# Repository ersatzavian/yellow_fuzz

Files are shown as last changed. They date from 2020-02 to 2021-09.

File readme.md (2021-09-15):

# Graduator

## What?

A bass fuzz for my good friend! Don't tell him, it's a surprise. Starting with a Boss MT-2 (I know, ew, don't tell anybody) because that's allegedly how Arion Salazar got most of his fuzz tone's on Third Eye Blind's self-titled (check out 2:20-2:30 in Graduate, of 4:10 in Thanks a Lot if you like yours with phaser). Hell yeah we want that, don't pretend you don't like that record. 

Formerly "yellow fuzz" after BRC's "yellow bikes" that happen to be green. Didn't like the sound of it, now it's the Graduator.

### Rev 01

Rev01 (non form-factor) has been built, brought up, and play tested. 

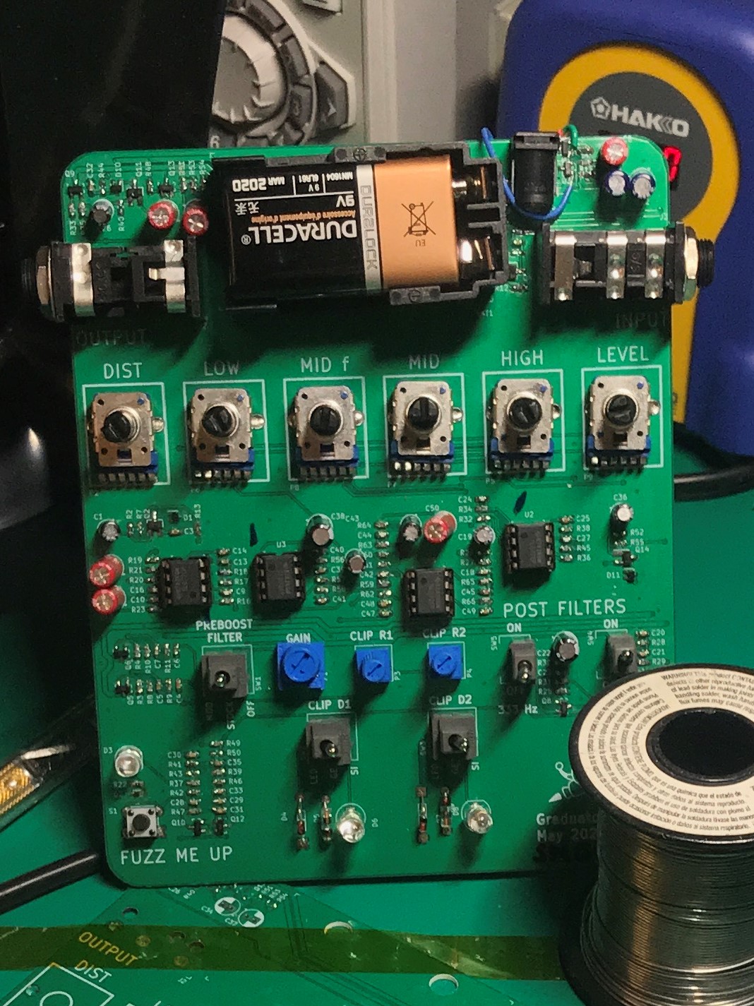
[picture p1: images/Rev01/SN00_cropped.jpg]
SN00


## Rev01 User Guide

[Electric Druid](https://electricdruid.net/boss-mt-2-metal-zone-pedal-analysis/) has an awesome write-up on the key circuit blocks in the original MT-2 design that's worth a read. If you want a comprehensive survey of the guts of this pedal, read that, then the mods section below, and you're done. 

### Controls

Controls are described by order in the signal chain, rather than physical layout. 

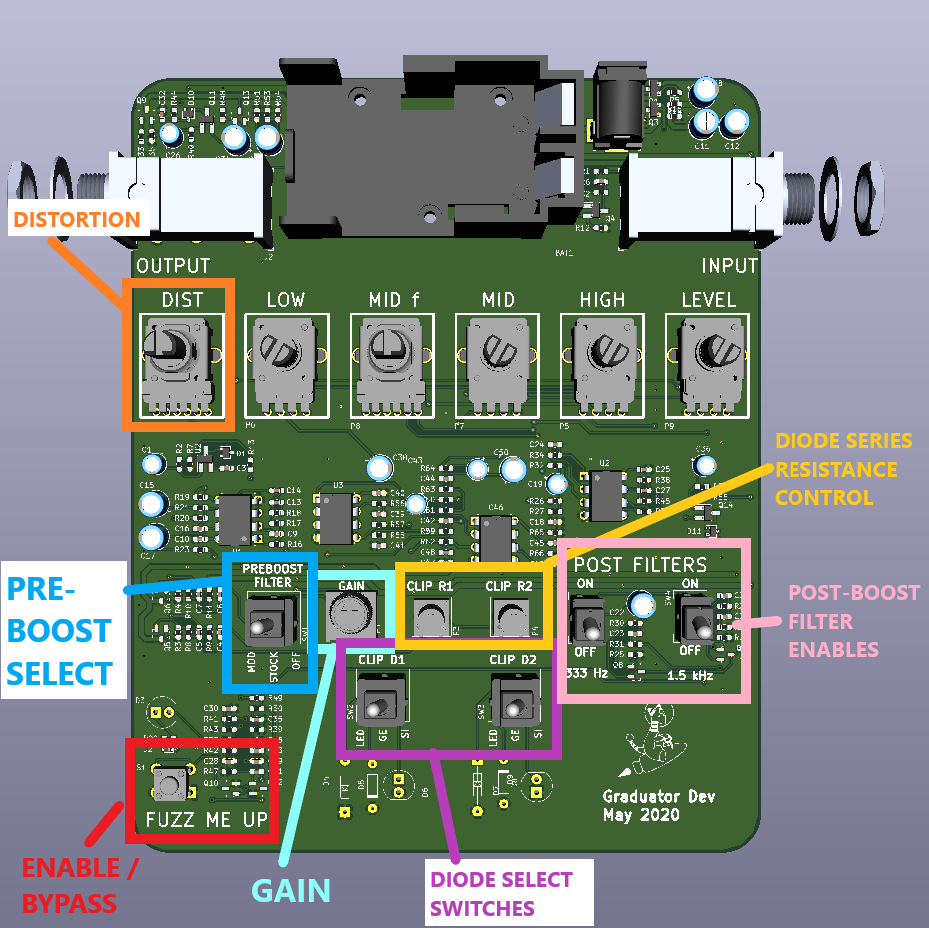
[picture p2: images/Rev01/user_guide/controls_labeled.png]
Rev01 Controls Labeled


| Control | Original MT-2 Control, or Experiment | Circuit Block | What's it Do? |
| --- | --- | --- | --- |
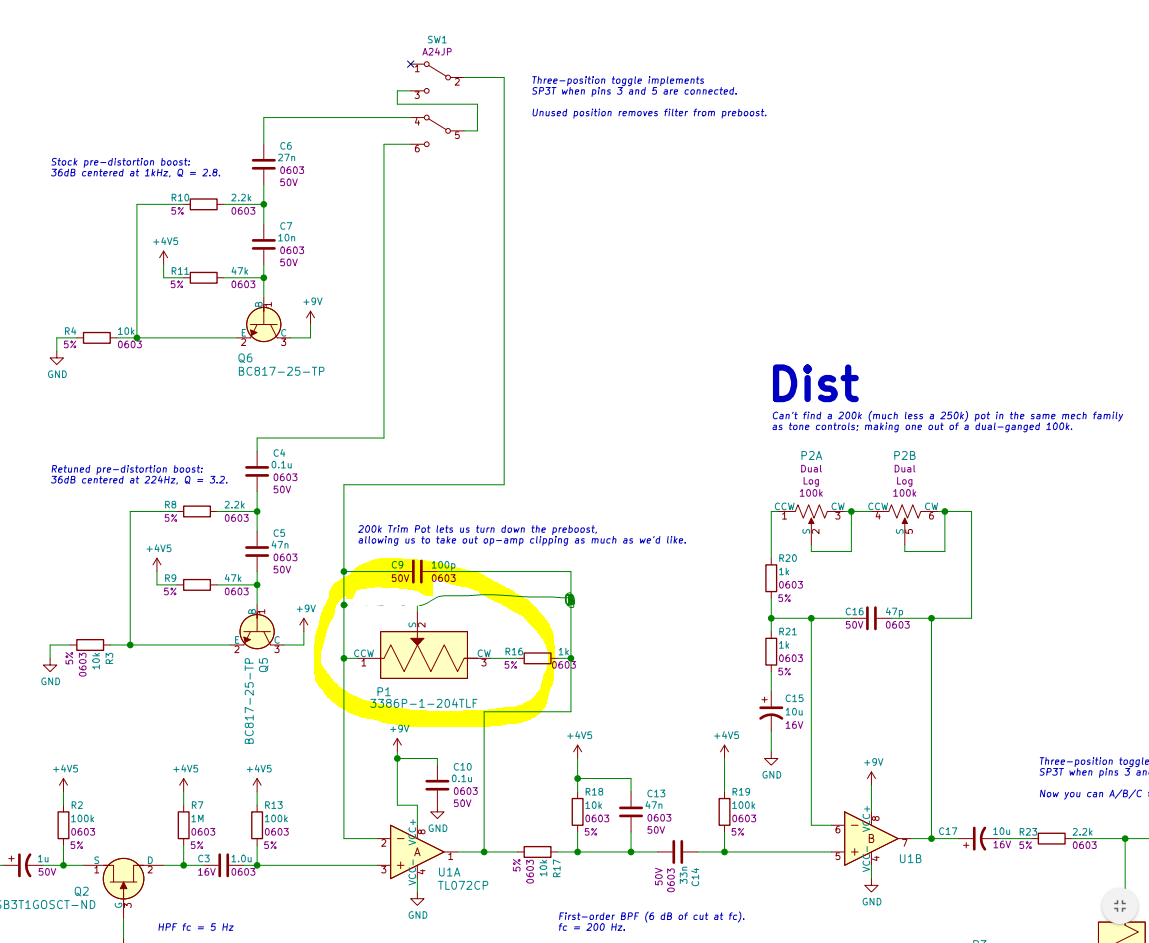
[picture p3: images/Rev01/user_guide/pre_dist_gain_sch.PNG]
Gain
| Gain | Experiment | Distortion Block - First Op-Amp Stage Gain, P1.  | The "pre-distortion" gain block does two things: <ul><li> Applies a band-pass-filtered boost (the center frequency of this boost has a mod described separately). </li><li> Demands enough gain from op amp U1A to cause some distortion when at high gain setttings. </li></ul> In the original MT-2, the gain of this stage is fixed. In the graduator, the feedback resistance here can be reduced, which reduces the gain. If the pre-boost filter is ignored (or the pre-boost filter select switch is used to skip the pre-boost filter), this control doesn't really do much at all; the end result of reducing the gain here is audibly identical to reducing the "Distortion" control. But with a filter selected, this control lets you choose how much that initial band-pass boosts, which can be kind of interesting. Definitely won't be included in the form factor design, but merits playing around with while you're playing the the pre-boost filter select. |
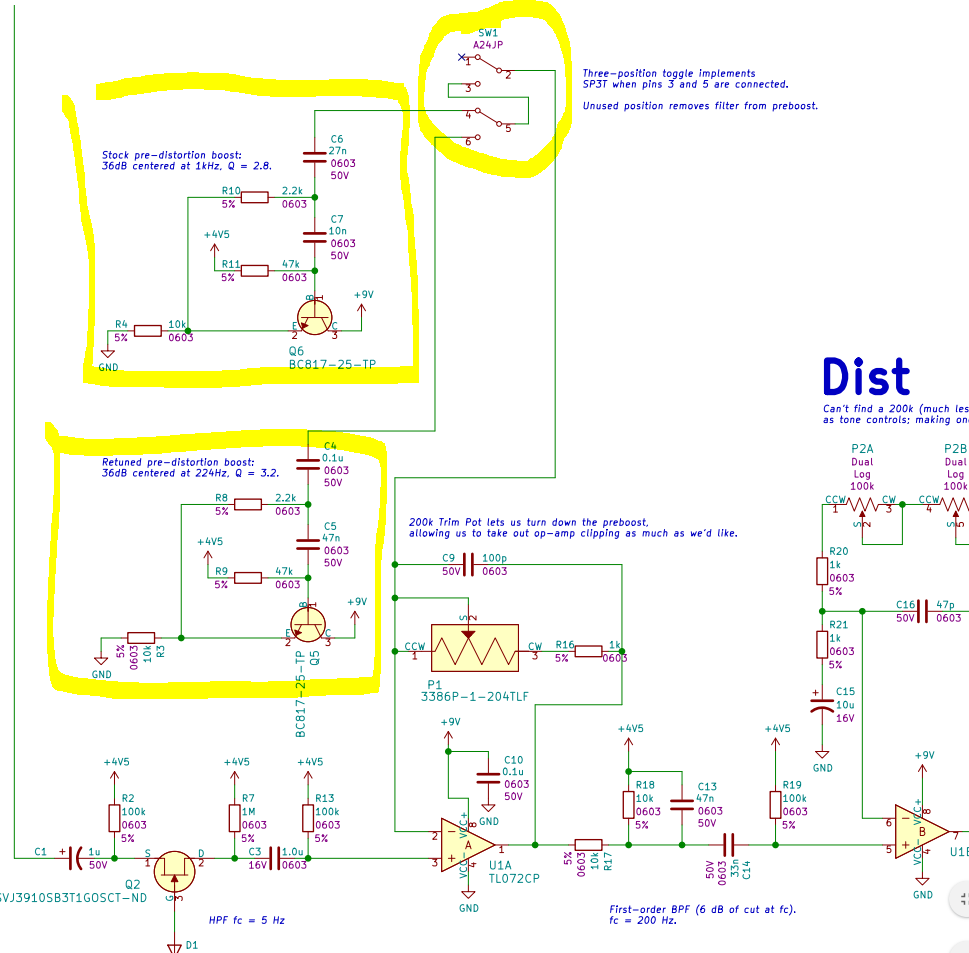
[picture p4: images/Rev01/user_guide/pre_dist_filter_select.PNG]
Pre-Boost Filter Select
| Pre-Boost Filter Select | Experiment | Distortion Block - First Op-Amp Stage Gyrator Select, SW1.  | As you can read about [here](https://sound-au.com/articles/gyrator-filters.htm), "gyrators" are nifty little active circuit blocks that let you make a thing that acts like an inductor out of a capacitor and a transistor or op-amp. Why not just use an inductor is a good question and is covered in that guide in good detail. For our purposes here, this control lets you pick between two filters, or a third disable setting: <ul><li> A stock filter which is described in the electric druid guide; it's a 36dB boost centered at 1 kHz with a "Q" of 2.8 ("Q", or "Quality Factor" describes how narrow and pointy that bandpass's frequency response is; a filter with high "Q" will be super pointy and really impact just its center frequency, while a filter with lower "Q" will be more gradual and wide and impact frequencies up and down the band around its center.).</li><li> A modified filter: 36 dB boost centered at 224 kHz, with a Q of 3.2. I made this mod to push the boost down into a range I thought might be better for a bass fuzz. </li><li> The disable setting just floats the switch terminal, which is kinda a bug because it takes the feedback (the "gain" control) out of the mix. You'll notice some volume variation going to and from this setting depending on where the "gain" is set. I may fix it. I may not. </li></ul>A bonus feature of this section is that one or both of these filter blocks could be retuned by changing a few parts, letting you do A/B comparison between a setting you like and a new setting you're considering. |
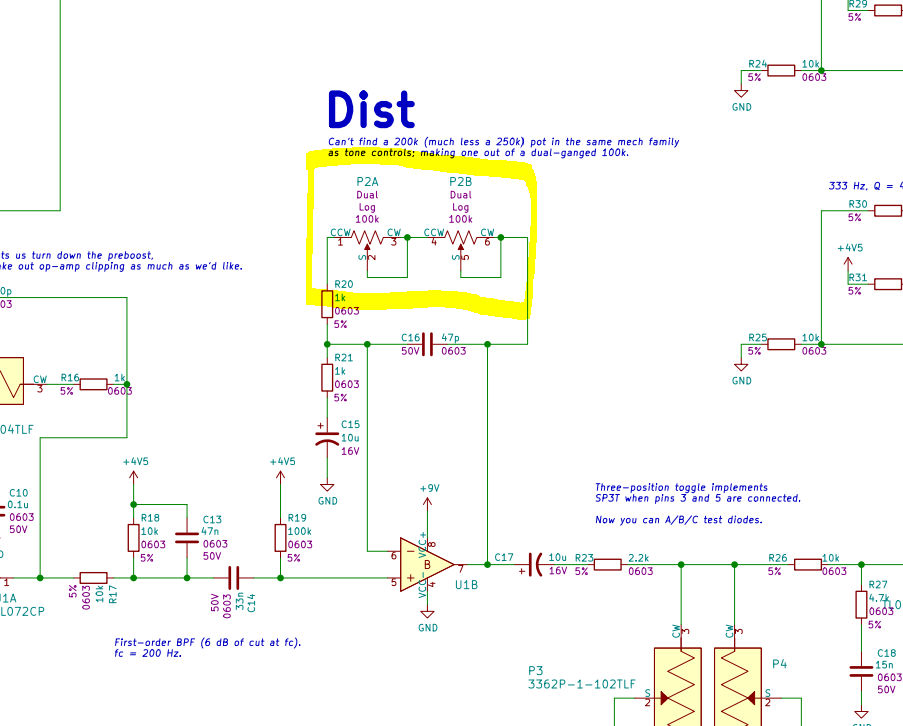
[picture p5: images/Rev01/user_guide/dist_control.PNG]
Distortion
| Distortion | Original | Distortion Block - Second Op-Amp Stage Gain, P2A/B.  | Controls the gain of the second op-amp stage before the diode limiter that really clips the signal. Running this op-amp at high gain will boost the signal to the "rails", and you'll get very hard, square peaks, before you even hit the diode limiter. There are many different sources of distortion in this pedal, it's definitely not all up to just one circuit block to hammer your signal into a mess. |
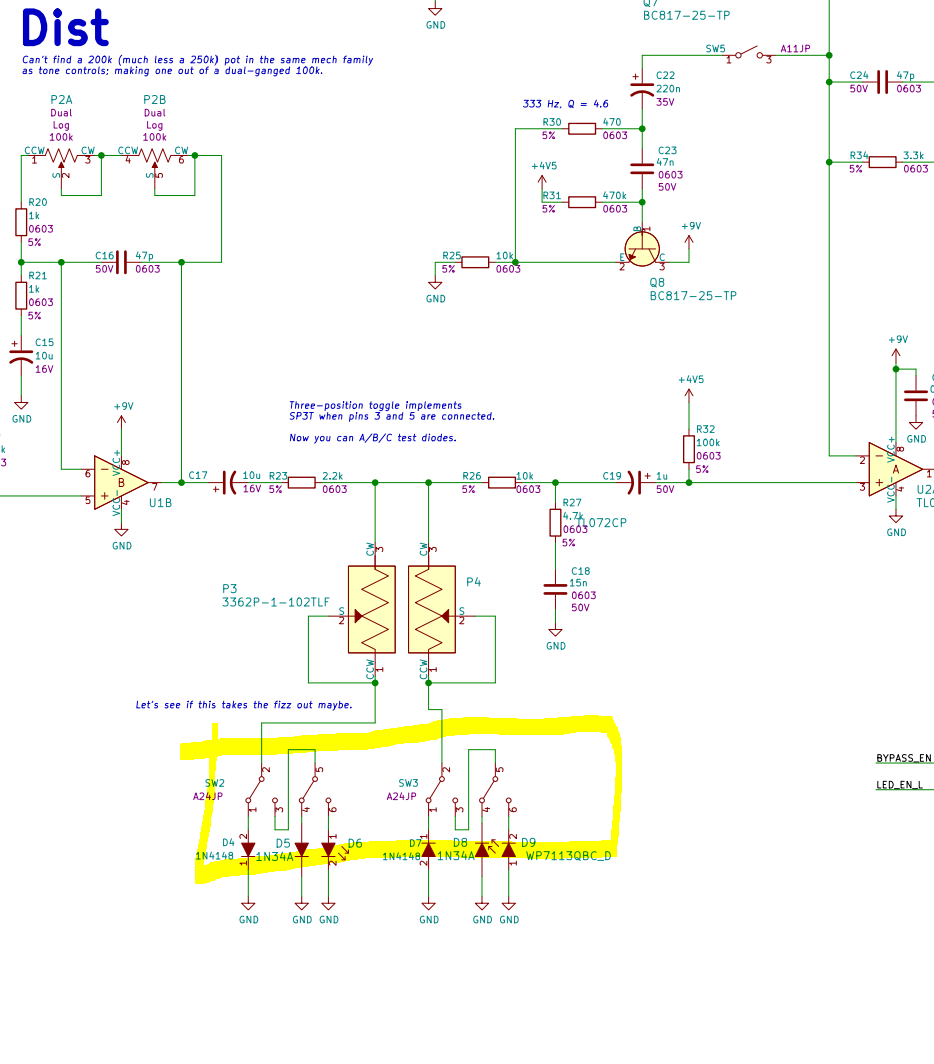
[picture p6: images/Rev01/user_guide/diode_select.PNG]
Diode Select
| Diode Select Switches | Experiment | Distortion Block - Diode Limiting Stage, SW2 / SW3  | The core of this pedal, as with many distortion pedals, is the diode limiter. This stage takes your nice sine-shaped waveform and clips the peaks off of it when they exceed the forward voltage of the diodes. Different diodes have different forward voltages, and different response "shapes" as they effectively turn on and off. The internet is full of forums where people will swear that this diode does this or that and sounds this way or that way, and many of them are subjectively right but nearly all of them are oversimplifying the test case they're talking about. Since there are so many sources of distortion in this (and every) circuit, you're hearing them all. The diode is just part of it. Anyway, this mod lets you pick between three different kinds of diode for your limiter. Even weirder, it lets you choose the diode for the top and bottom half of your waveform separately, so you can produce very "asymmetric" distortion. Right now, you have: <ul><li> A Silicon diode, the generic [1N4148](https://www.diodes.com/assets/Datasheets/ds12019.pdf), with a forward voltage around 1V. </li><li> A Germanium diode, the generic [1N34A](https://www.nteinc.com/specs/original/1N34A.pdf), with a forward voltage around 1V. </li><li> An LED, [Kingbright WP7113QBC/D](https://www.mouser.com/datasheet/2/216/WP7113QBC-D-58299.pdf). This is a blue LED, and has a forward voltage of not less than 2.4V. This is really a bug; I should have used a red or yellow LED with a forward voltage closer to the other two, so that you could compare tone without comparing volume - you'll notice right away that the blue LED is louder than the other diodes. I like how it sounds, though, so I'm considering that a future experiment and letting it ride. </li></ul> Just like the pre-distortion boost section, this section is a great place to swap out components you're curious about and A/B test stuff. |
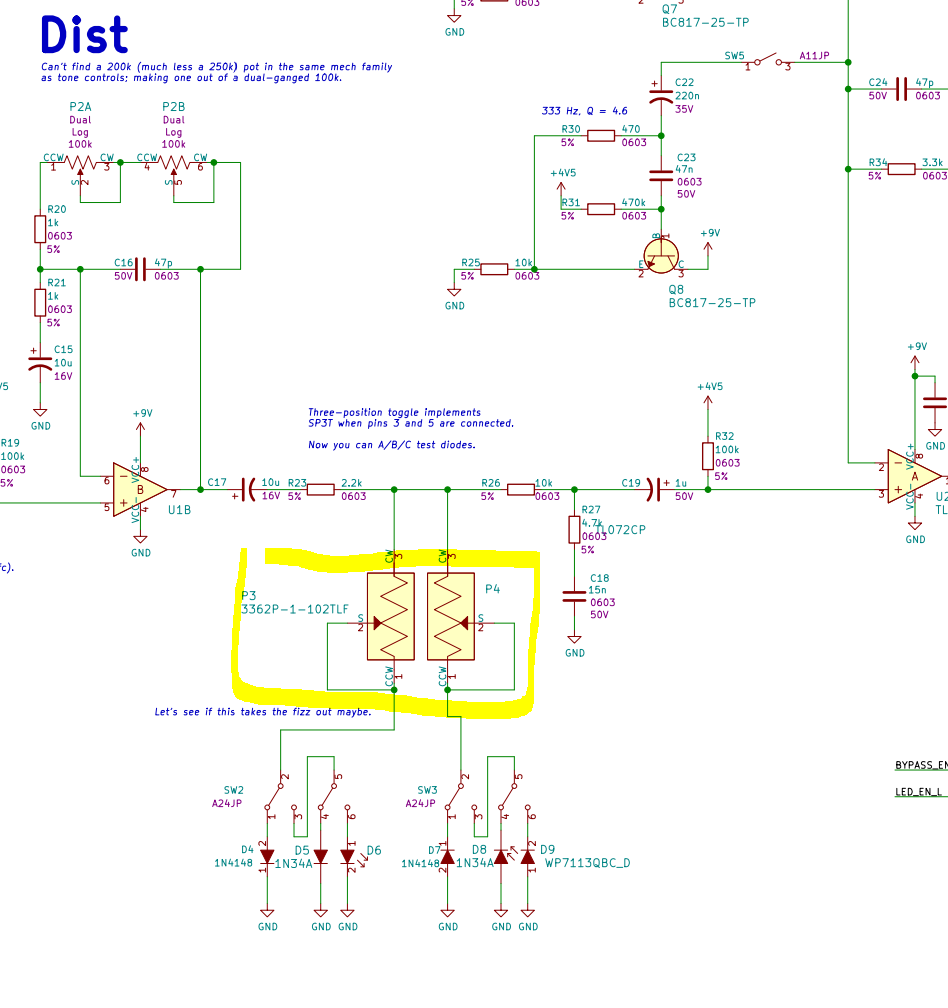
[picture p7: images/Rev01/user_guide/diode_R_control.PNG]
Diode Resistance Control
| Diode Series Resistance Control | Experiment | Distortion Block - Diode Limiting Stage, P3 / P4.  | Diode clipping can be very harsh and introduce harmonics that you wouldn't get from, say, output stage distortion in a tube amplifier, which can sound really buzzy and cheap and not great. In an attempt to prevent this, I added 1k potentiometers - variable resistors - in series with the diodes, to soften the "knee" when they turn on and off and try and reduce that fuzz. In practice, the EQ section of this pedal has way, way more impact on the harmonic content that makes it out of the pedal, and I find this control completely inaudible. |
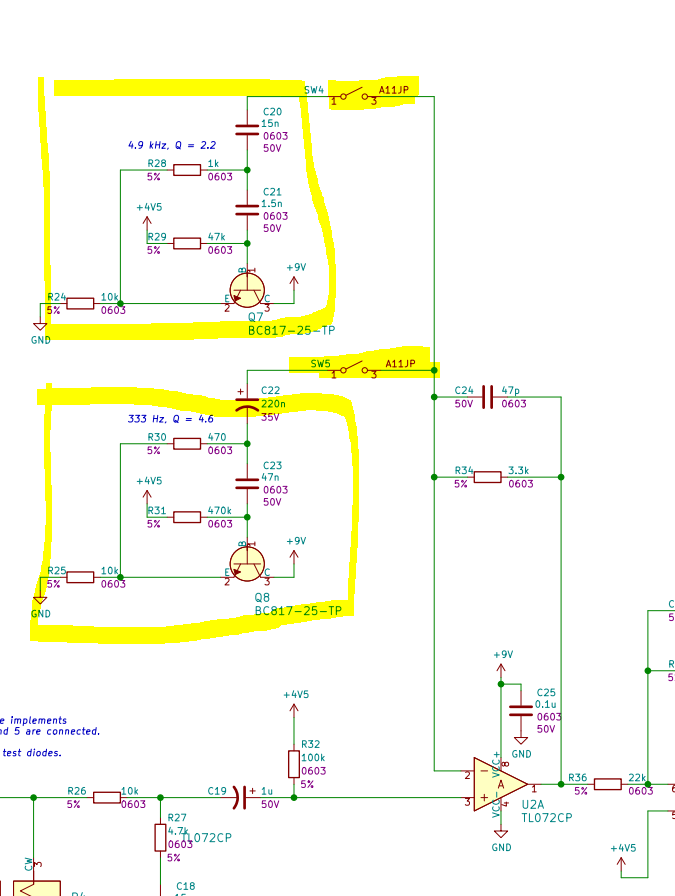
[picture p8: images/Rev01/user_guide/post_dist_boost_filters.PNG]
Post Boost Filter Control
| Post-Boost Filter Enables | Experiment | Distortion Block - after Diode Limiting Stage, SW4 / SW5.  | The original MT-2 includes this stage with both Gyrator sections included, which provides a "double-humped" bandpass boost. In the original, the two sections are: <ul><li> A ~5dB boost at 105 Hz with Q=14.6. </li><li> A ~10dB boost at 4.9 kHz with Q=2.2. </li></ul>In the graduator, the two sections are: <ul><li> A ~5dB boost at 333 Hz with Q=4.6. </li><li> The original ~10dB boost at 4.9 kHz with Q=2.2. </li></ul>There are really two mods here: <ul><li> I've moved the lower peak up the frequency spectrum and fattened it up a bit. </li><li> Both peaks can be enabled or disabled with the respective switches. </li></ul> This is a little more subtle to play with than I expected, and I like that. Try it out. |
| EQ - Low | Original | Tone Block | The original "low shelf" control, a band-pass filter centered at 105 Hz with a Q of 3.1, which can provide up to 20dB of cut or boost. The whole EQ section is covered very nicely with plots in the Electric Druid guide, highly recommend. |
| EQ - Mid Frequency | Original | Tone Block | The original "mid frequency" control, which controls the center of the mid band-pass filter. Filter center frequency can be swept from about 200 Hz to about 7 kHz. This control would be a lot better as a log taper pot, to spread the frequencies of interest logarithmically along the range of the pot, but a dual-ganged log-taper 50kΩ pot is not an easy thing to find. As a result, you'll hear this control really come to life between about 1 o-clock and 5 o-clock. |
| EQ - Mid | Original | Tone Block | Cut or boost up to 15 dB with the mid-band filter centered wherever you put it with the Mid Frequency knob. |
| EQ - High | Original | Tone Block | High Shelf EQ, begins to kick in around 1kHz, where it offers around 6 dB of cut or boost, and flattens around 10 kHz, where it offers around 20 kHz of cut or boost. | 
| Level | Original | Tone Block | You know what this does. | 
| Enable / Bypass | Original | Switching Section | You know what this does too. |

## Mods

| Change | Goal | Done |
| --- | ---- | ---- |
| Make gyrators after clipping stage optional (see C24/C25, C20/C17) | Experiment with pedal character to reduce fizz and deliver more even tone to the eq section so I can hear the difference. | Yes |
| Add bypass option for preboost stage. | Try to reduce fizz. | Yes |
| Add series variable resistors (trim pots) to clipping diodes D3/D4. | Try to reduce fizz. | Yes |
| Add selector switch for 3 different diode options in each direction. | Experiment with higher Vf (LEDs) and give germanium a whirl. | Yes |

## Issues

### Rev01 (Non-Form-Factor)

| Issue | Workaround | Fix | Fixed in Master |
| ----- | --- | --- | --- |
| C2 and R6 ref designators are swapped. HTML BOM shows correct outlines. | Install per HTML BOM. | Swap ref des back. | |
| R4, R6-7, R12, R14-15, R17-18, R24-26, R33, R51 MPN is for 1k part, should be 10k (part description on BOM is correct, but MPN is wrong). | Install 10k part. | Update component in lib. | | 
| R14 and R15 ref des are colliding. | N/A | Fix in layout. | |
| NSVJ3910SB3T1G was replaced in order with J113, which is a through-hole part and won't fit. | Order correct part. | Make sure MPN in design is correct and orderable. | |
| PTV111-4420-A104 was missing from kit, got extra PTV112-4420-A104 instead. | Cut leads 1 and 2, bend 3-6 down to fit into pads 1-4 to use just one pot of the two in the package. | Order the right thing. | |
| PTV111-4420-A503 was missing from kit, got extra PTV112-4420-A503 instead. | Cut leads 1 and 2, bend 3-6 down to fit into pads 1-4 to use just one pot of the two in the package. | Order the right thing. | |
| Nichicon UST1H010MDD1TE footprint is wrong (C1, C19, C26, C36, C43, C46): lead spacing is nto correct, part leads are flared for wider spacing than footprint. | Bend leads back. | Correct footprint. | | 
| D6 missing MPN info. | N/A | Correct part library ref. | |
| No test points, doh. | N/A | Add some ground test points and stage-to-stage test points and jumpers. | |
| 22 Ohm series-R on power rail, why even would you do that? | Short that. | Remove that. | |
| Polarity marks on op-amps are not visible enough, and are obscured when sockets are installed (U1 was installed rotated 180 degrees in first build). | Note polarity carefully during build. | Improve op amp polarity marks. | |
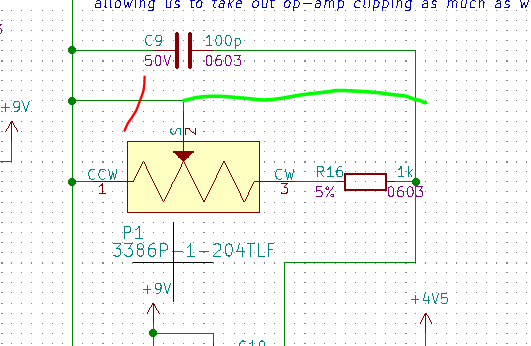
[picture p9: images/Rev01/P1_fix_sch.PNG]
Sch
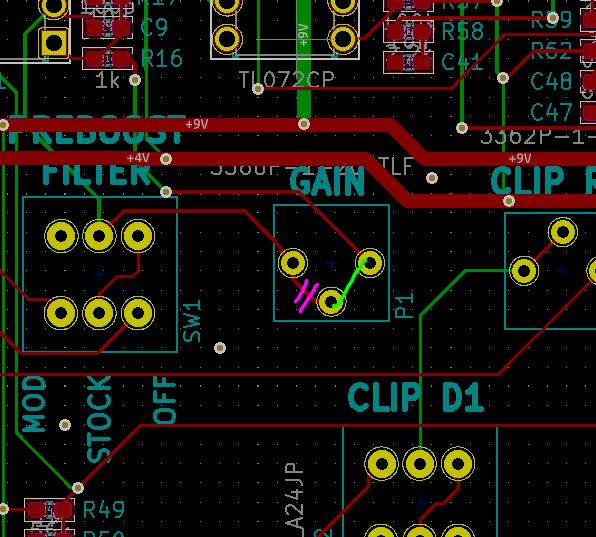
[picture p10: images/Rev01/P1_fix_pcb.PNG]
Layout
| Pre-distortion boost gain pot P1 is backwards (CCW for more) | Turn it the other way, or snip top-side trace between pins 1-2, short pins 1-3.   | Correct in schematic. | |
| Dual pots installed in P5, P6, P7, and P9 with pins 3-6 slid over into pads 1-4 don't match design correctly. | Double-check pinout of these parts and revise rework used to place dual pots in single-pot footprints. | Use the parts on the BOM, duh. | |
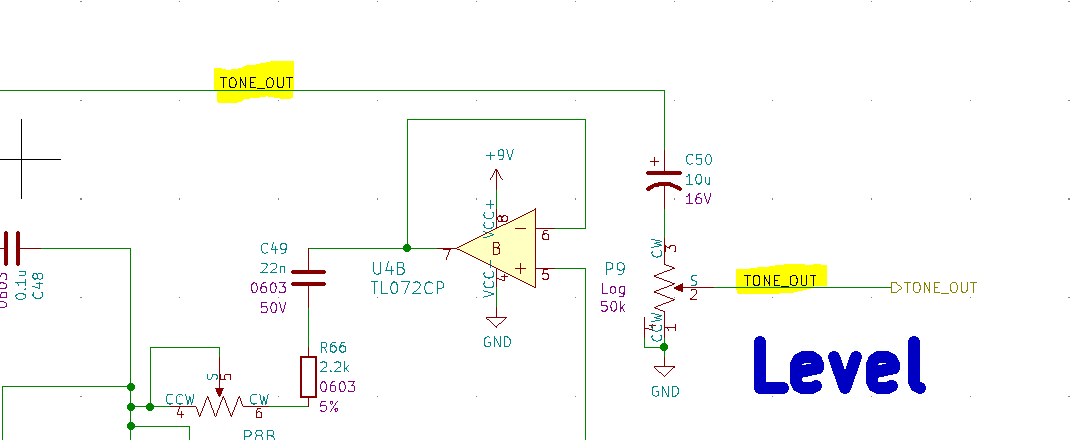
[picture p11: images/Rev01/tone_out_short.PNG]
Tone Out Issue
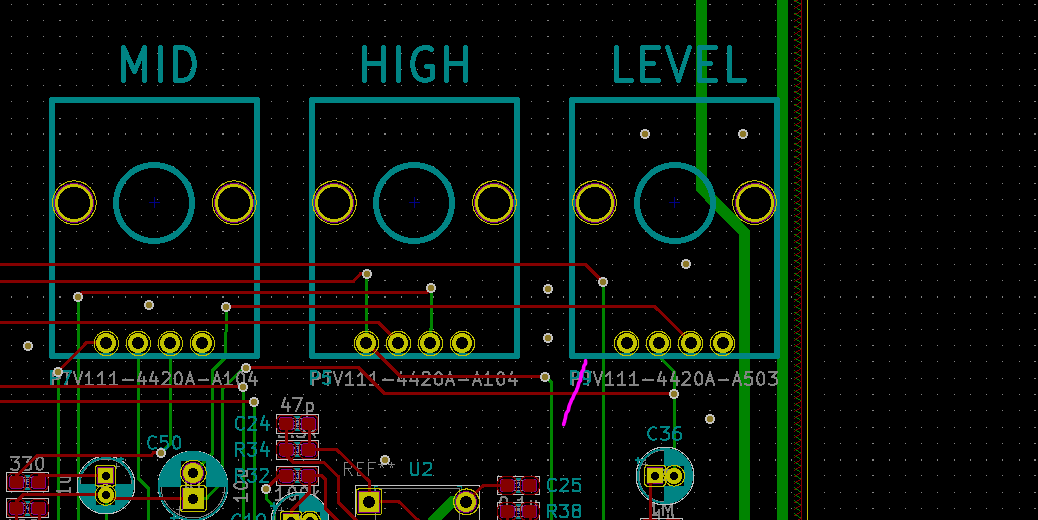
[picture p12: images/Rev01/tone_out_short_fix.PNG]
Tone Out Workaround
| Duplicate TONE_OUT net names caused short across level pot.  | Cut extra trace on top layer.  | Remove duplicate net label. | |
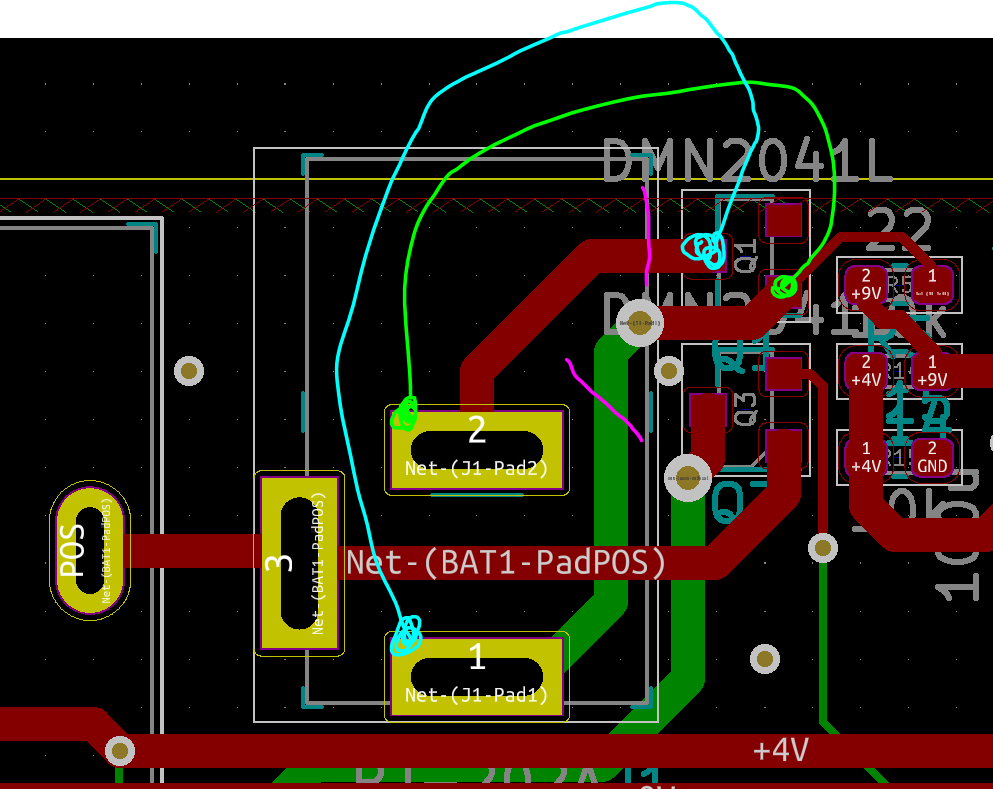
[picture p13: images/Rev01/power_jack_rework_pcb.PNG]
Jack Rework
| Incorrectly routed jack as center-positive, which makes the battery not work at all. | Cut and swap traces to make center-negative.  | Permanentify rework. | |
| Mid frequency control only does much between about 1-o-clock and 5-o-clock. | Use as is. | Try once more to find a log pot... good luck. | |
| Pre-boost filter select switch SW1 should probably have a resistor on its unused pole, rather than having fixed gain and taking the "gain" control out of the mix. |  |  |  |

## Parts Needed

### For Rev02 (Form-Factor)
* 1/4" Stereo Jack, Panel Mount with header footprint.
* 1/4" Mono Jack, Panel Mount with header footprint
* Re-evaluate all potentiometer tapers and footprints.

## Play testing notes

* It sounds... like an MT-2 with some stuff changed. 
* The pre-filter change is the most interesting, as swapping diode types. 
* Post-filters are also interesting, but a bit less so. 
* Still many settings that produce lots of unpleasant fizz. Tonally I'd still say it's "mostly bad with the ability to do some good things."
* Series-R on the dioes does exactly nothing. On the scope, it does visibly soften the knees a little, but by the time this has been through the tone section, that does the same thing. 
* Secondary control on the initial boost gain does exactly the same thing as the drive control. Might try playing with it a bit more with the pre-filter set to off, but for the most part just set it to 10 and leave it. 

## References

### Other Pedals I'm eyeing
* DOD FX91 Bass Overdrive
* Darkglass - Duality
* Zvex - Wooly Mammoth
* Death by Audio - Fuzz War
* Bass Big Muff
* MXR Bass Fuzz
* Fairfield Barbershop

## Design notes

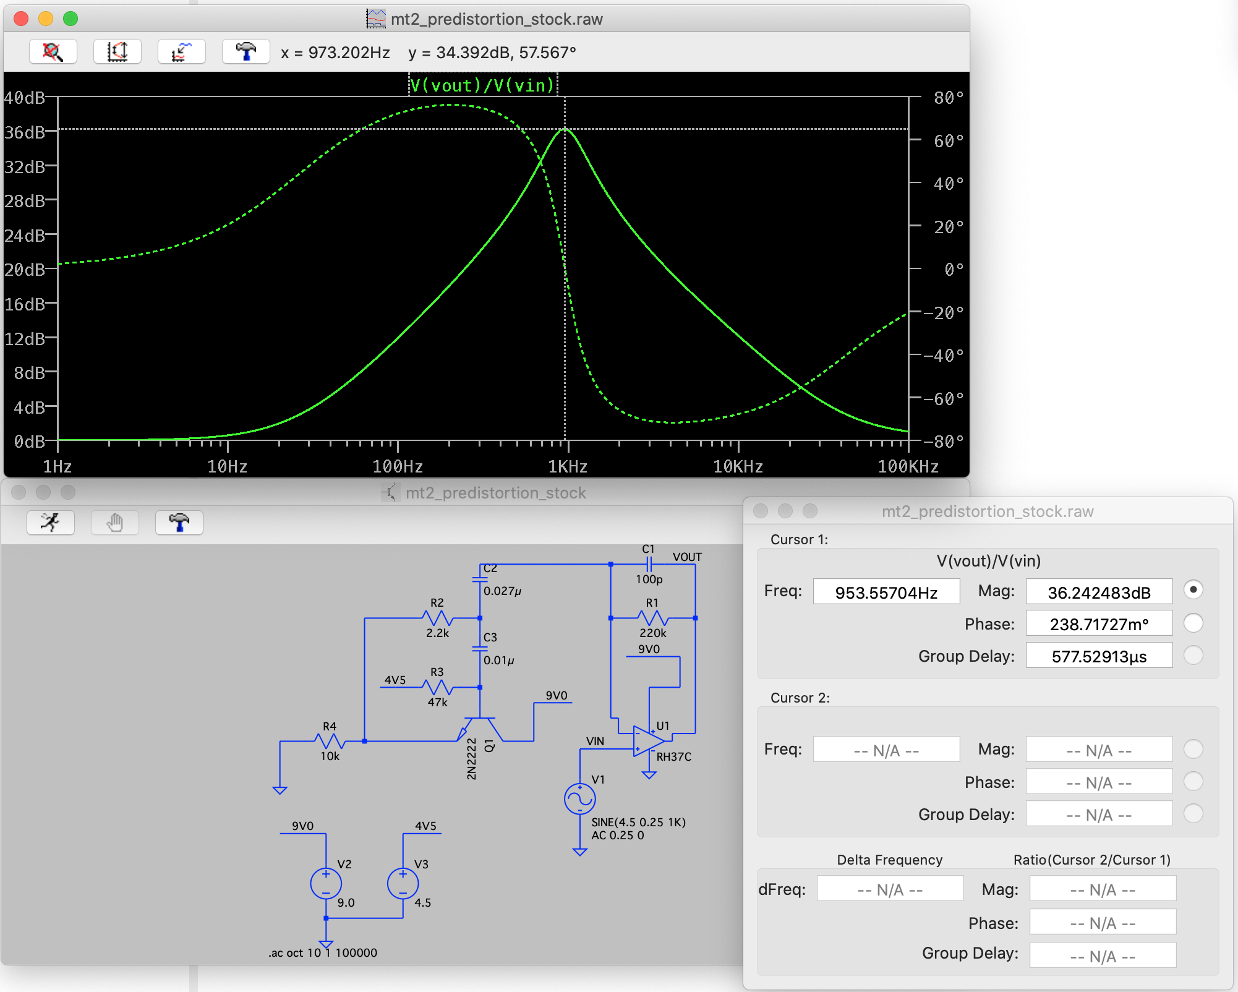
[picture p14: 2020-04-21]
sims/images/predistortion_bpf_stock.png

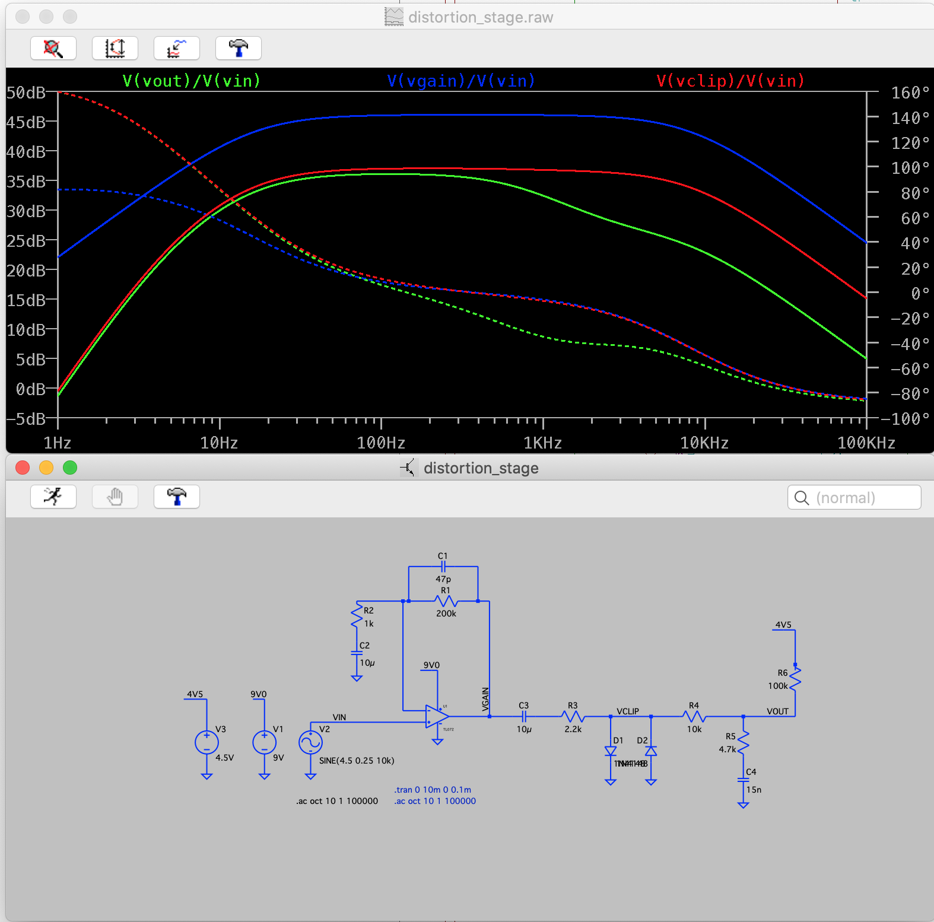
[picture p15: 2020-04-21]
sims/images/distortion_frequency.png

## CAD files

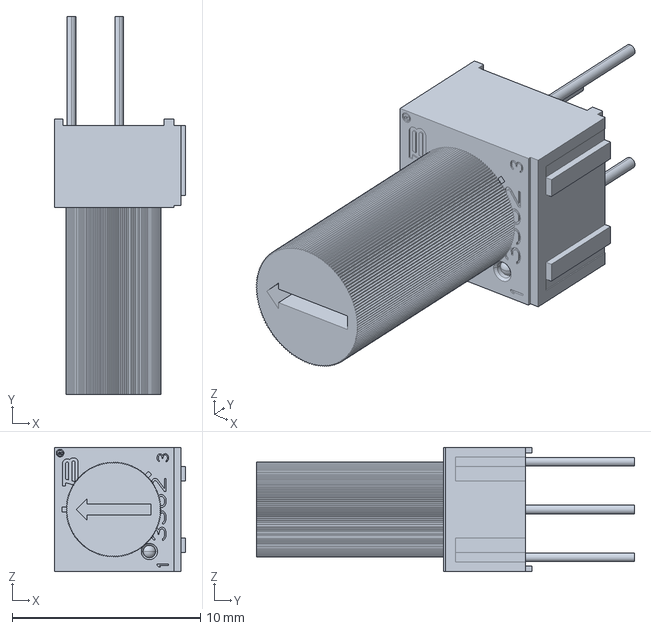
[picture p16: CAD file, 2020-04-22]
parts/3362-T.stp
6.98 x 20.1 x 6.60 mm

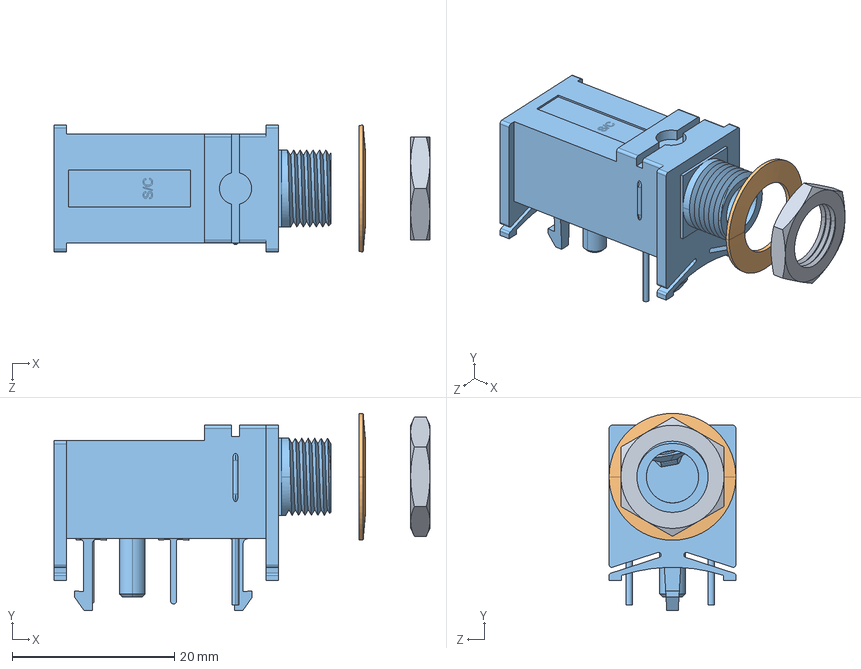
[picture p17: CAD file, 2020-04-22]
parts/SN49C12B_FreeState.STEP
46.3 x 24.3 x 15.6 mm

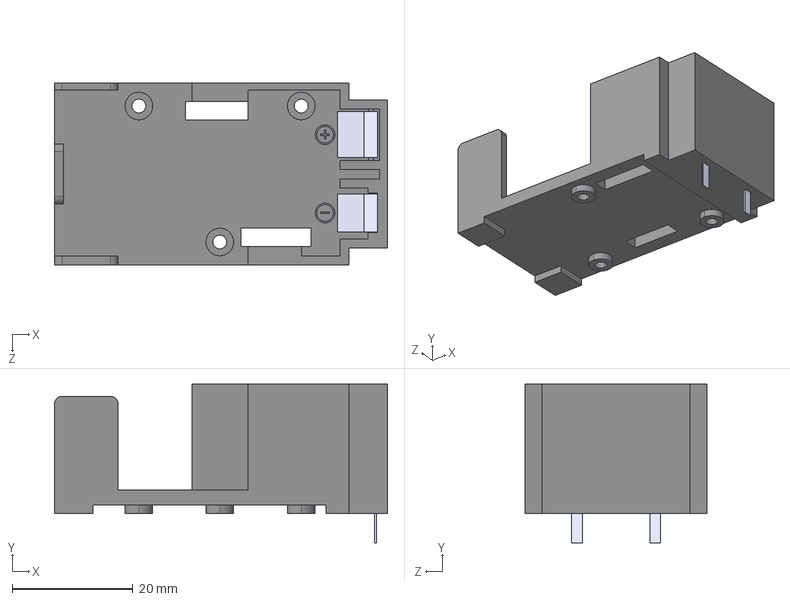
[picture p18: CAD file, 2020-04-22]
parts/BC9VPC.STEP
55.1 x 26.3 x 30.1 mm

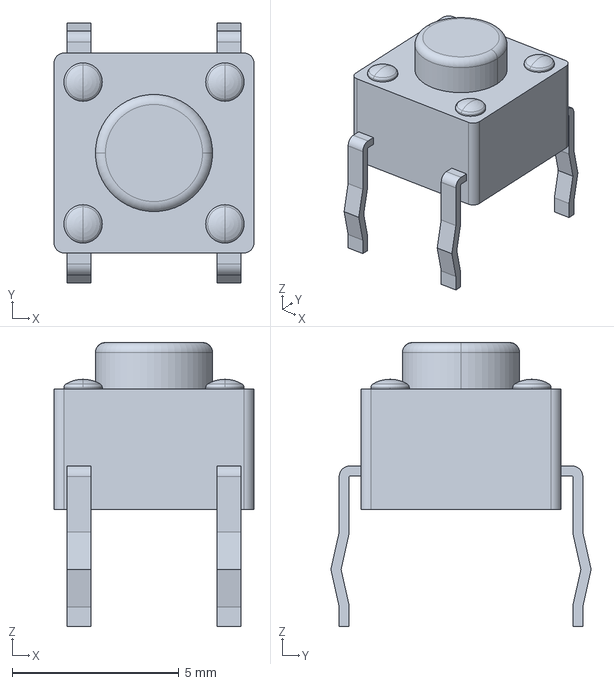
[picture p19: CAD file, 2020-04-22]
parts/c-1825910-6-c-3d.stp
5.99 x 7.80 x 8.51 mm

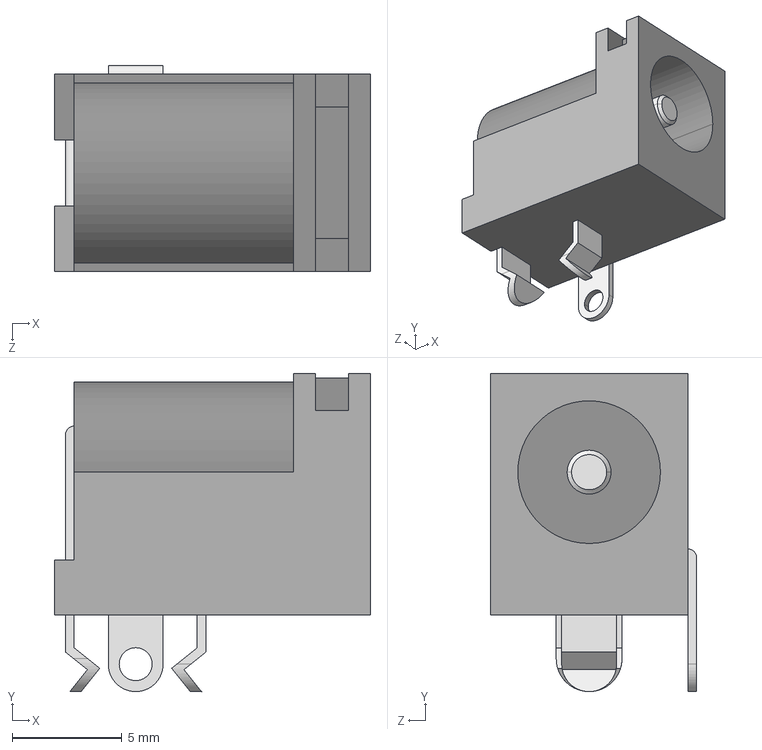
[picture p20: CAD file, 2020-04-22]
parts/CUI_DEVICES_PJ-202A.step
14.4 x 14.5 x 9.40 mm

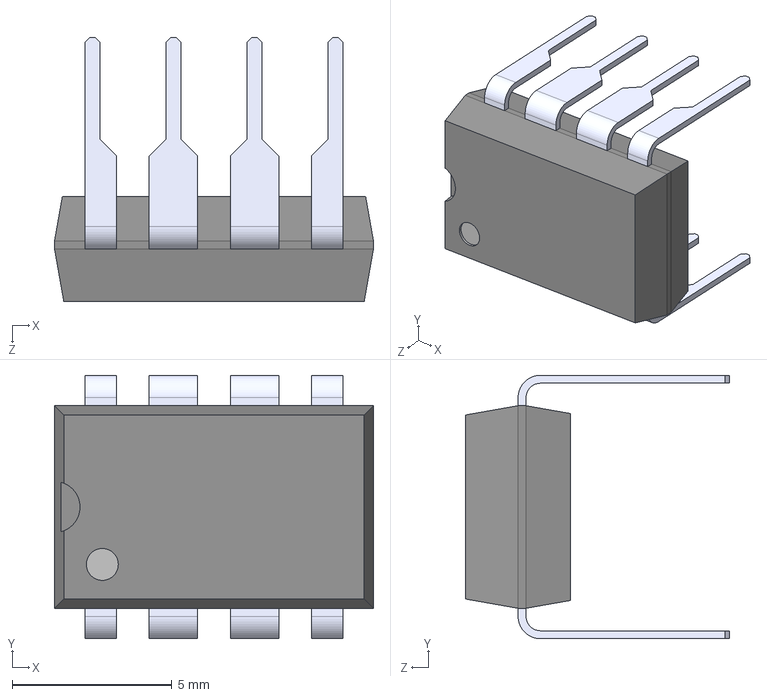
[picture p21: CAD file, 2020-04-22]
parts/User Library-PDIP-8.step
10.0 x 8.26 x 8.28 mm

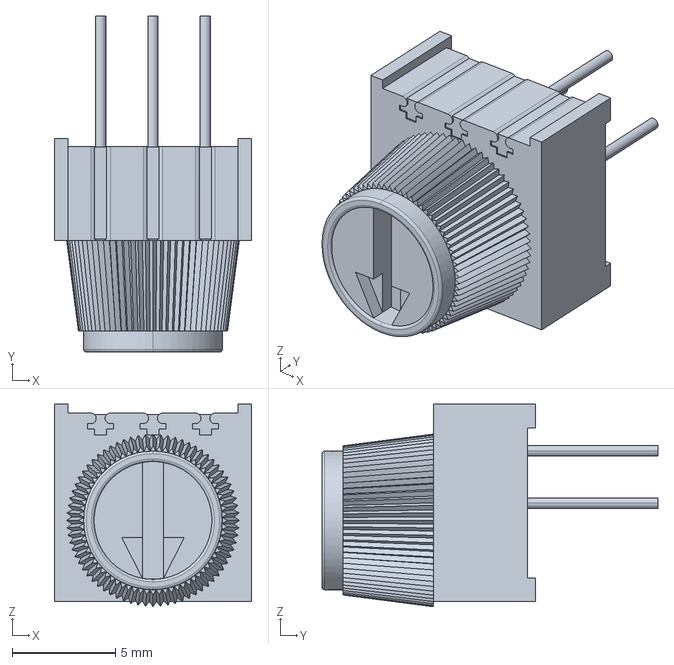
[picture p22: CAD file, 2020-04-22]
parts/3386P(T).stp
9.58 x 16.3 x 9.83 mm

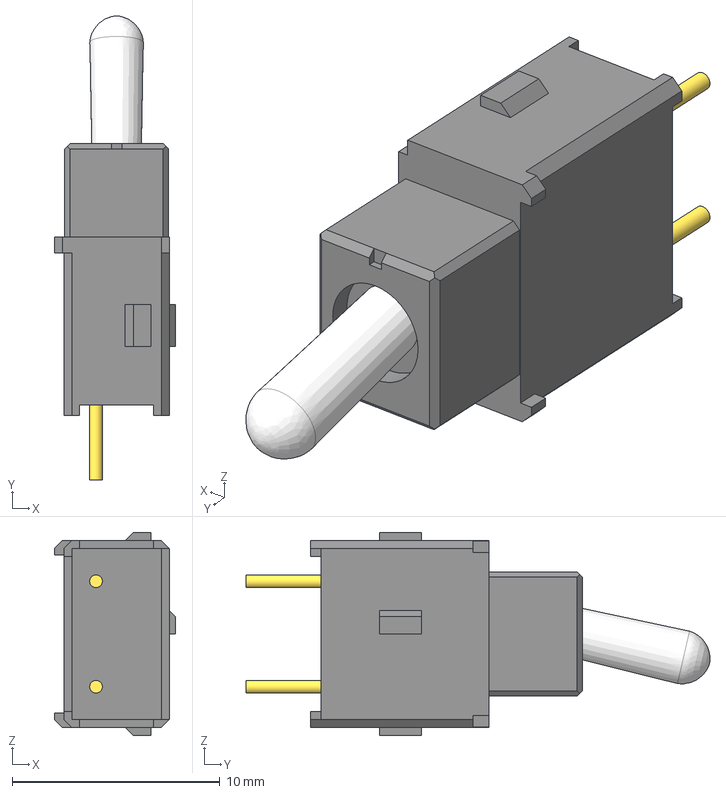
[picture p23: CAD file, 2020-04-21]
parts/A11JP.stp
5.84 x 22.4 x 9.80 mm
_A1-toggle-body
_A11P-toggle-terminals
_AJ-toggle-toggle

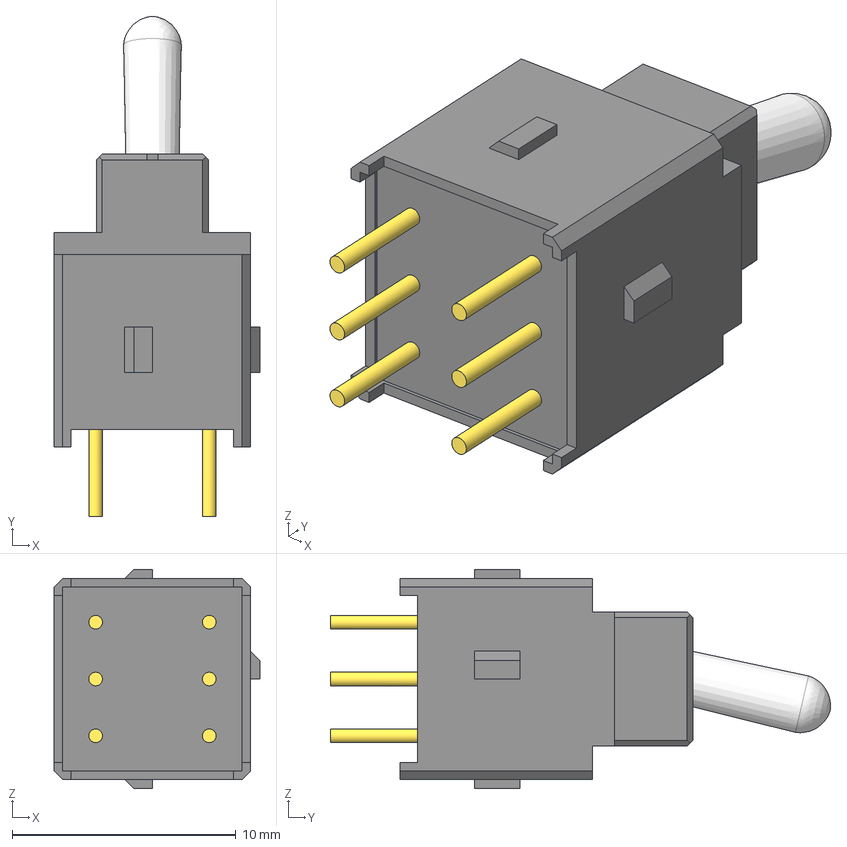
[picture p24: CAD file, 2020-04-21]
parts/A24JP.stp
9.19 x 22.4 x 9.80 mm
_A2-toggle-body
_A24P-toggle-terminals
_AJ-toggle-toggle

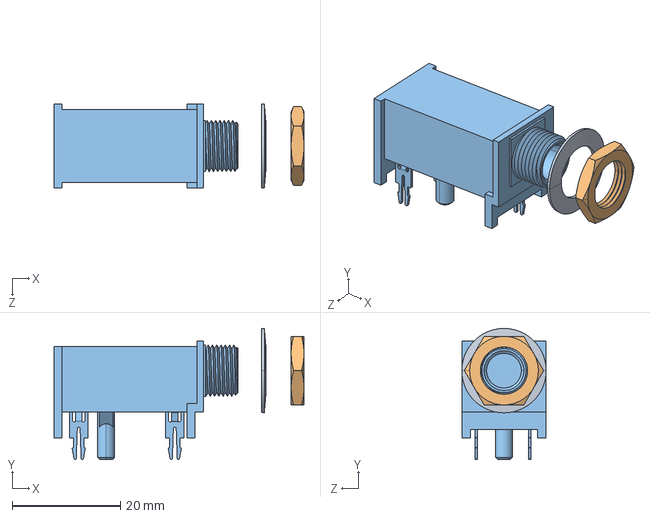
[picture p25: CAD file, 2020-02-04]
parts/RA49B12A.STEP
46.3 x 24.3 x 15.6 mm

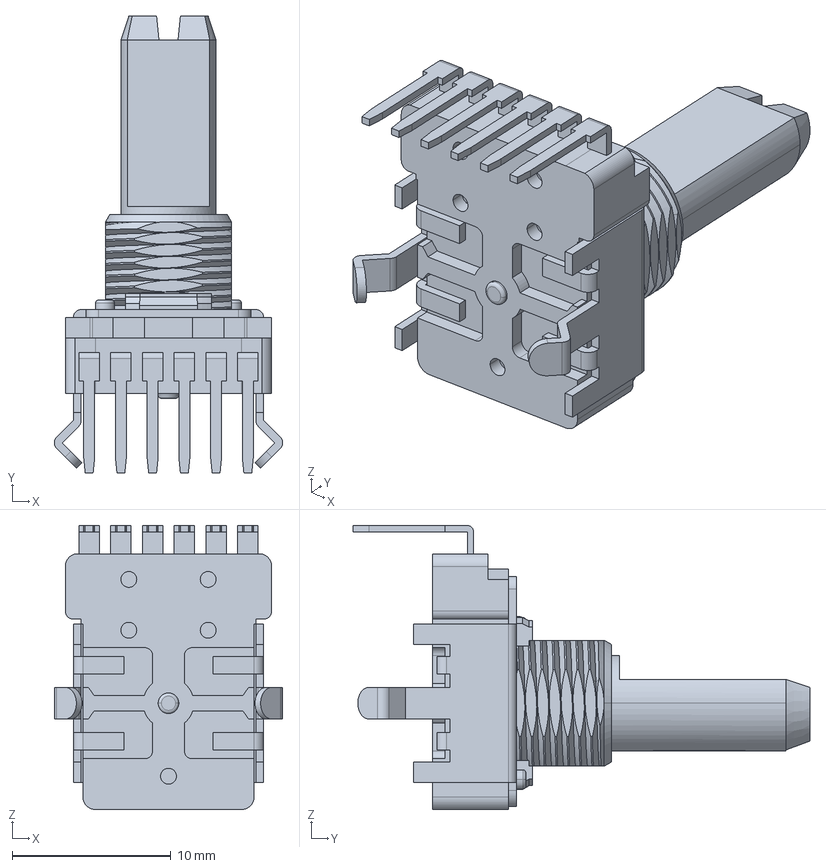
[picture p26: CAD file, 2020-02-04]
parts/ptv112-3417a-xxxxx.stp
14.4 x 28.8 x 17.9 mm

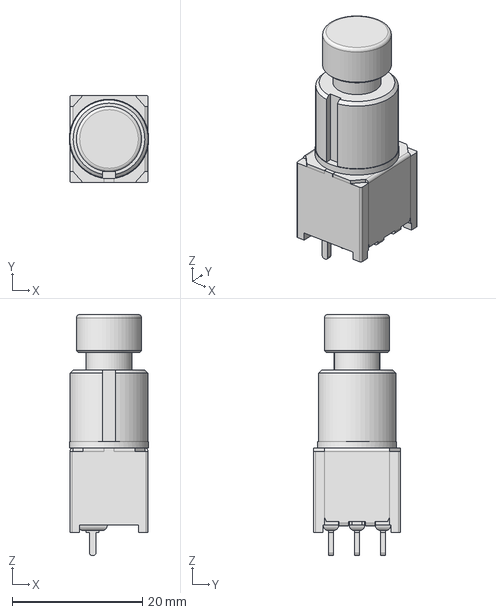
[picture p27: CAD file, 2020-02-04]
parts/FS5700SPMT2B2M2QE.stp
12.2 x 13.4 x 37.0 mm

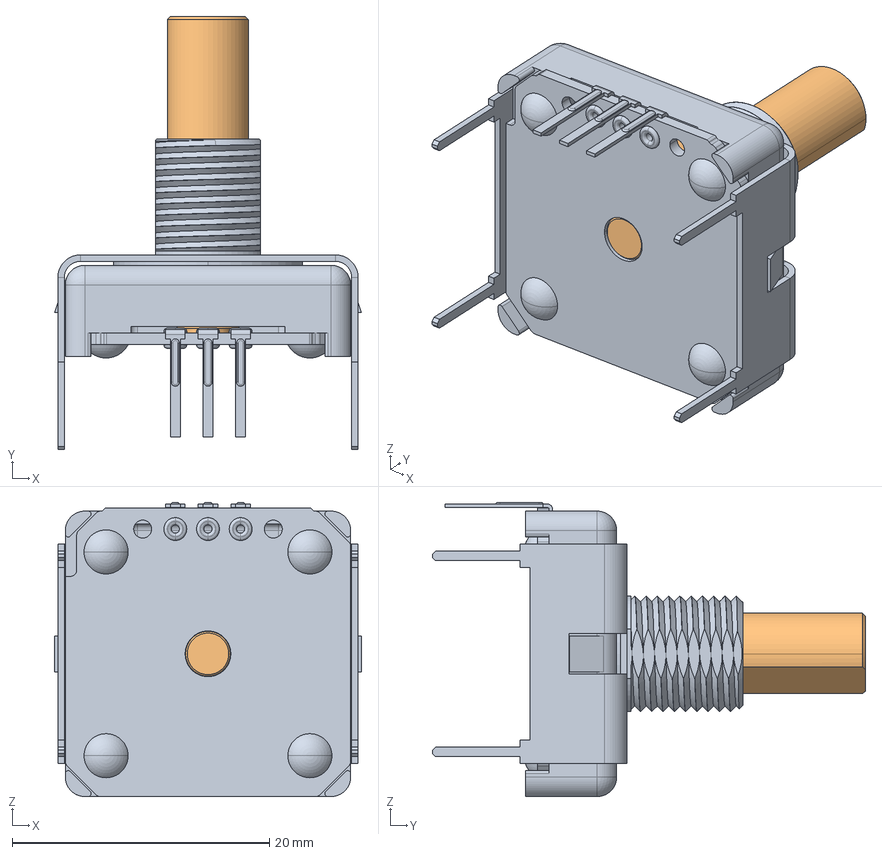
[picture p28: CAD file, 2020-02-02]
parts/pcl1d-c24-bab.stp
23.9 x 33.7 x 22.9 mm

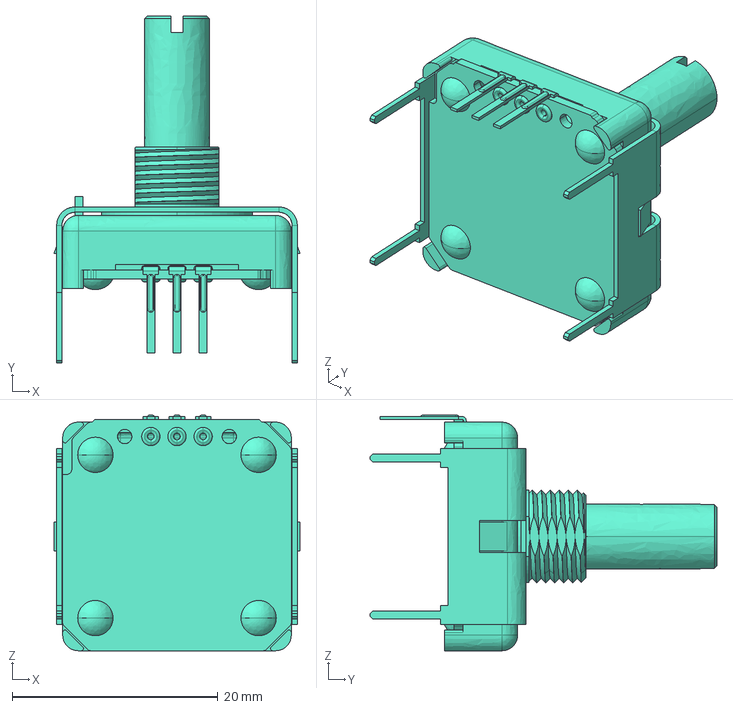
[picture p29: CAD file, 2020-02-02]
parts/pcw1j-b24-kcb.stp
23.9 x 33.7 x 22.9 mm

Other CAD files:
parts/PTV111-4420A.stp
parts/3362P001XXX0A.stp
parts/PCW1J-R24-BAD252/Allegro/pcw1jr24bad252.psm
parts/PCW1J-R24-BAD252/DEHDL/pcw1j_r24_bad252/chips/chips.prt

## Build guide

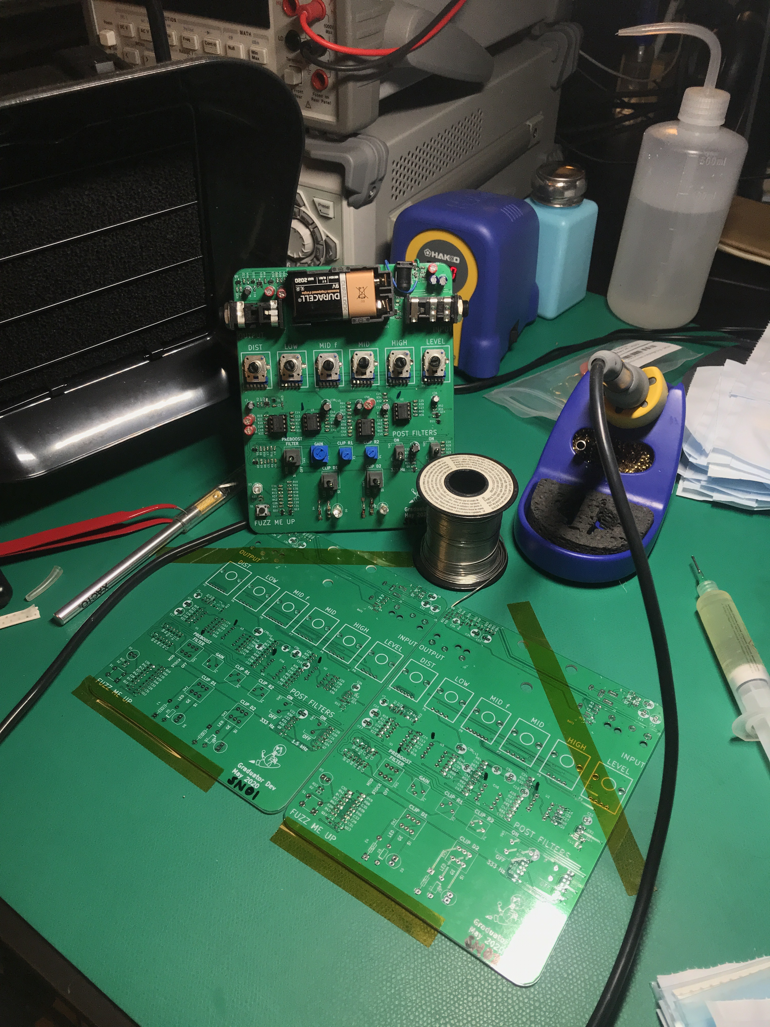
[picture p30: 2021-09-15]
images/Rev01/SN00_02_build.JPG

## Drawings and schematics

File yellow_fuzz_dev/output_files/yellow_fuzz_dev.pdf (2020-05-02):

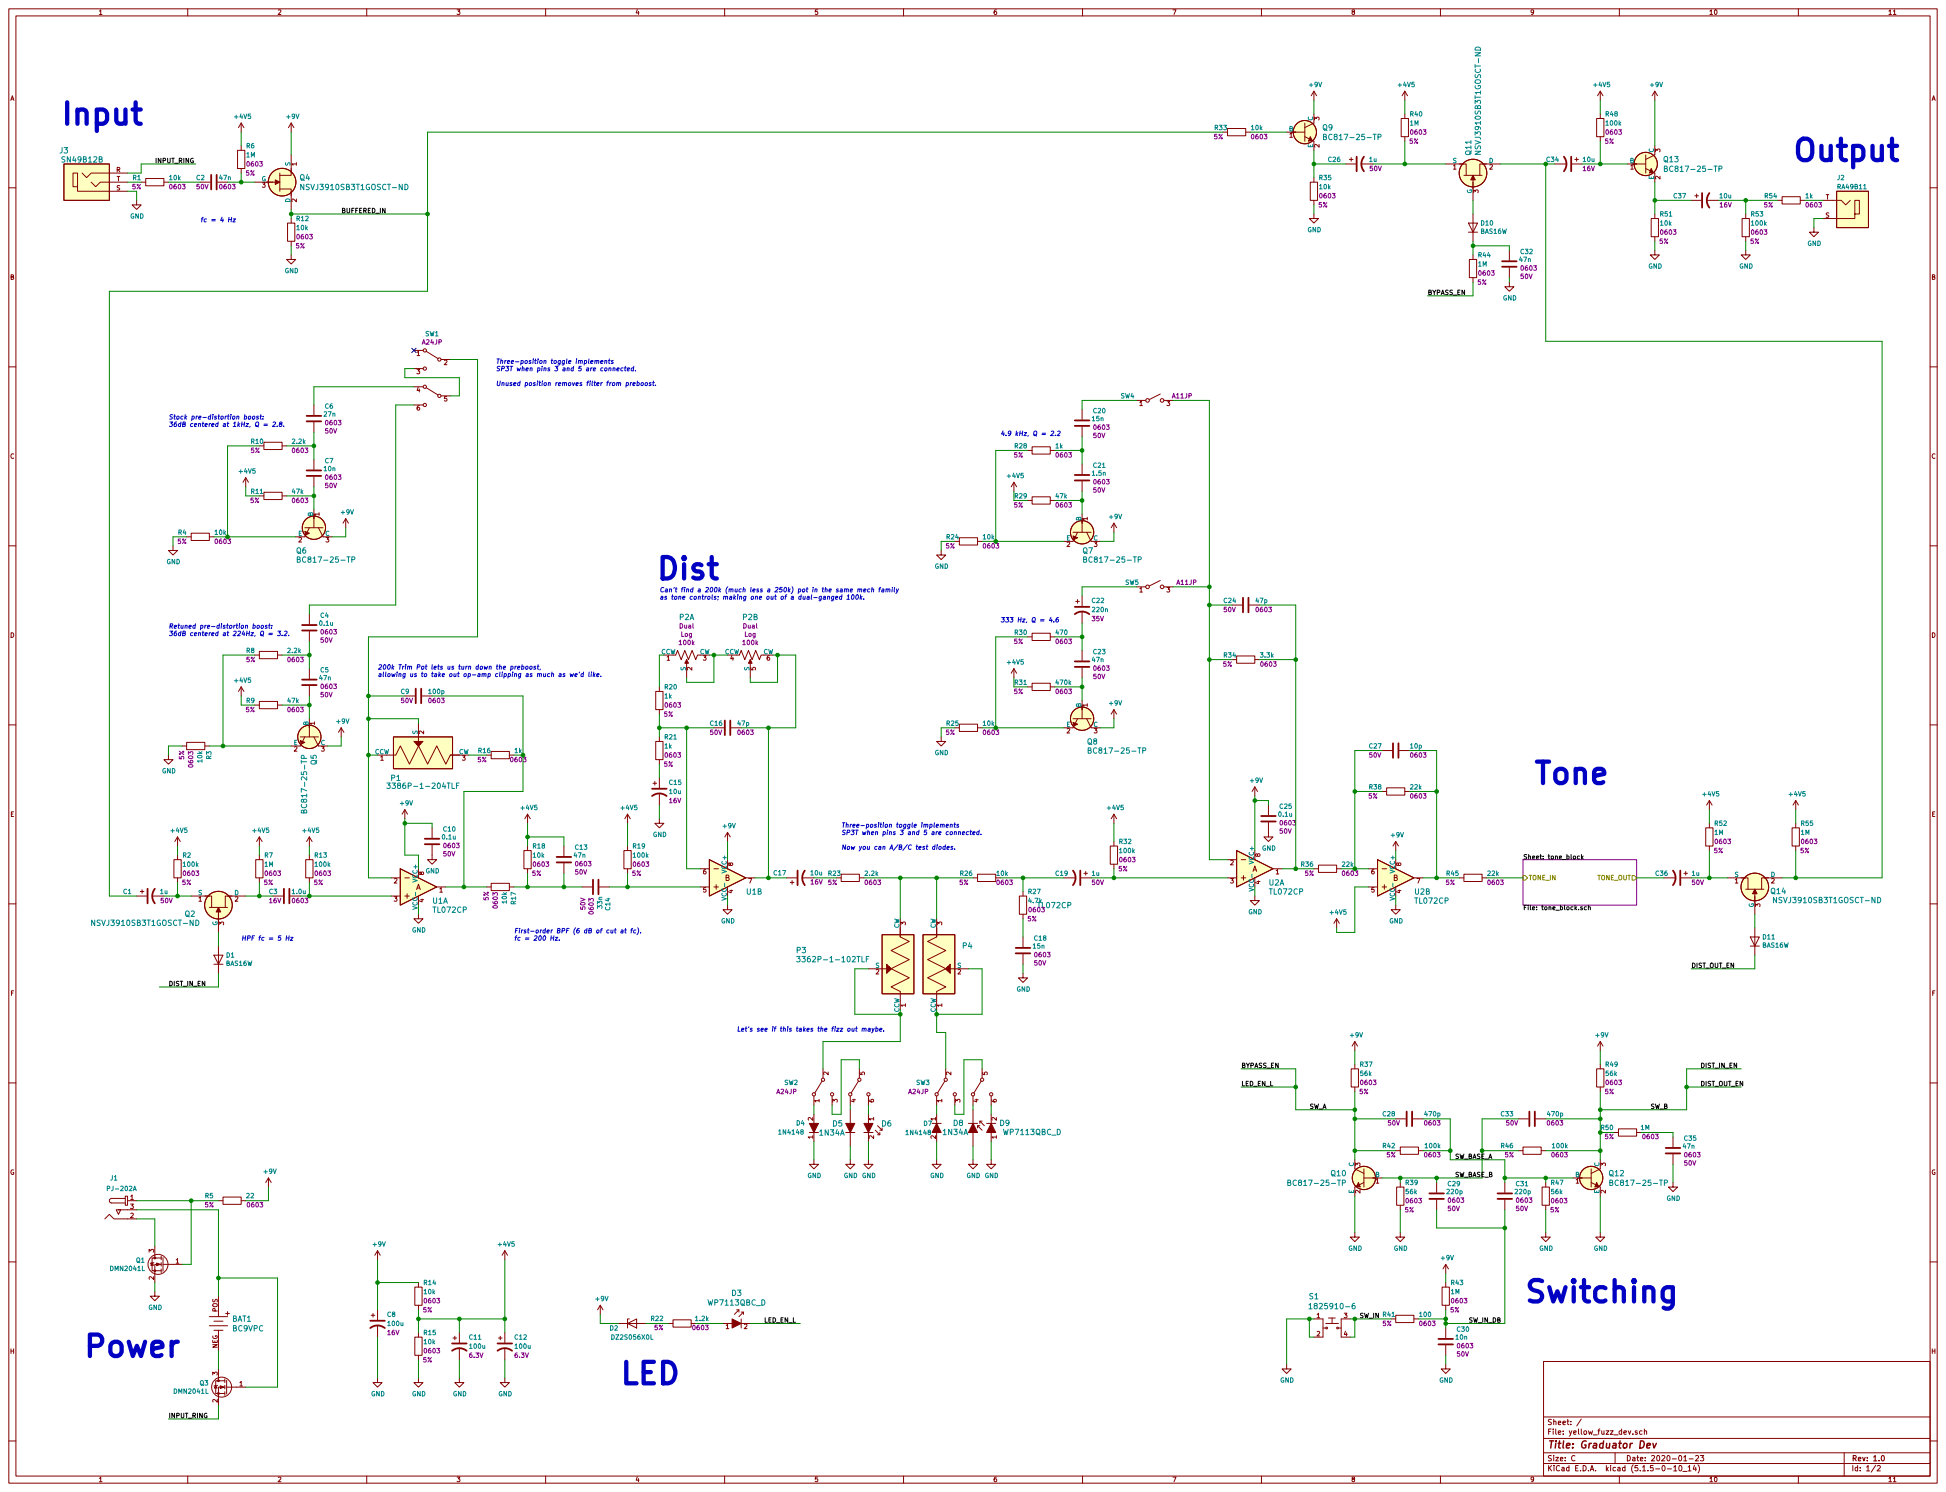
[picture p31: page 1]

Three-position toggle implements
SP3T when pins 3 and 5 are connected.

Unused position removes filter from preboost.

Cant find a 200k (much less a 250k) pot in the same mech family

allowing us to take out op-amp clipping as much as wed like.

Now you can A/B/C test diodes.

First-order BPF (6 dB of cut at fc).

Lets see if this takes the fizz out maybe.

File: yellow_fuzz_dev.sch Sheet: /
Id: 1/2 Title: Graduator Dev

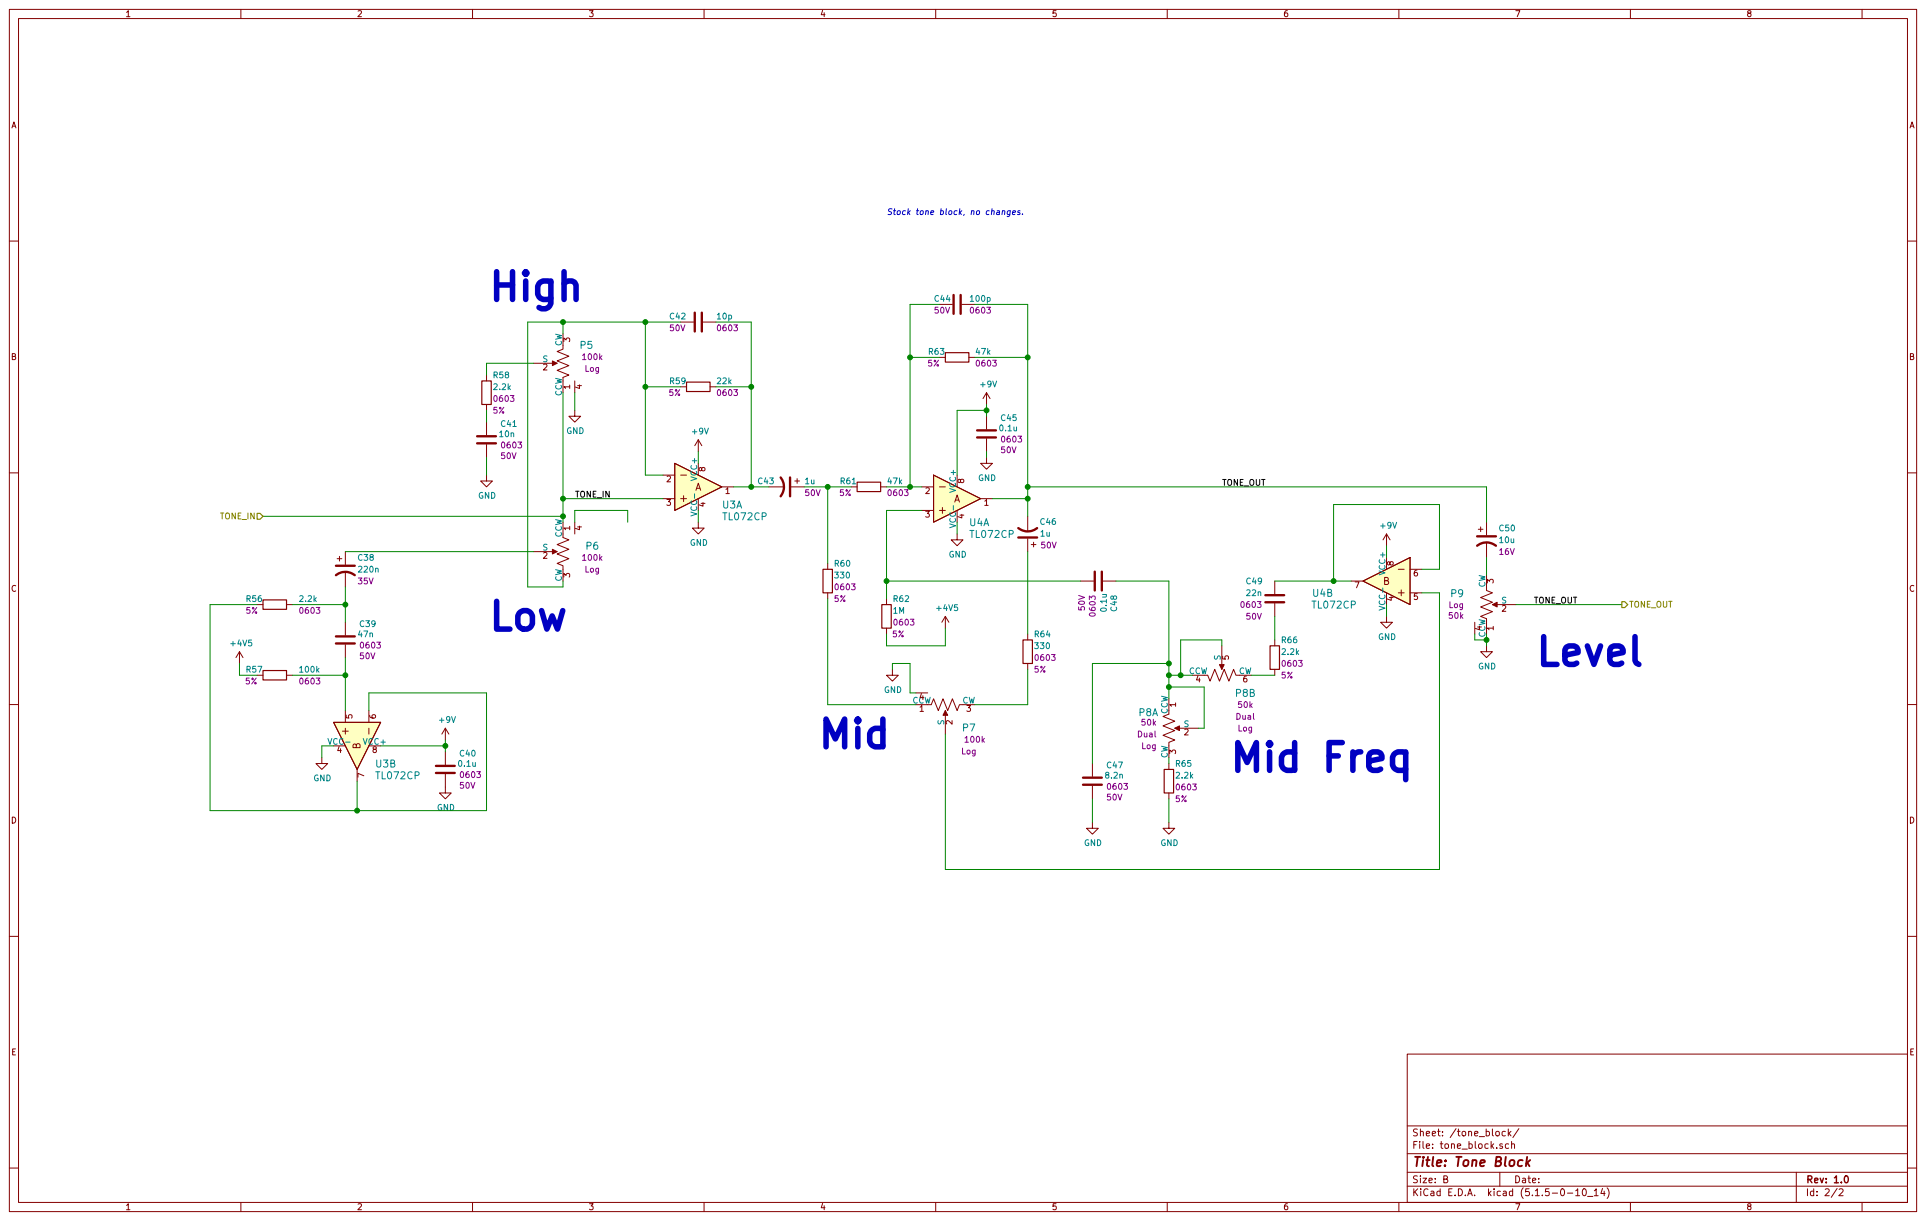
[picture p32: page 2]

Stock tone block, no changes.

Sheet: /tone_block/
File: tone_block.sch
Id: 2/2 Title: Tone Block

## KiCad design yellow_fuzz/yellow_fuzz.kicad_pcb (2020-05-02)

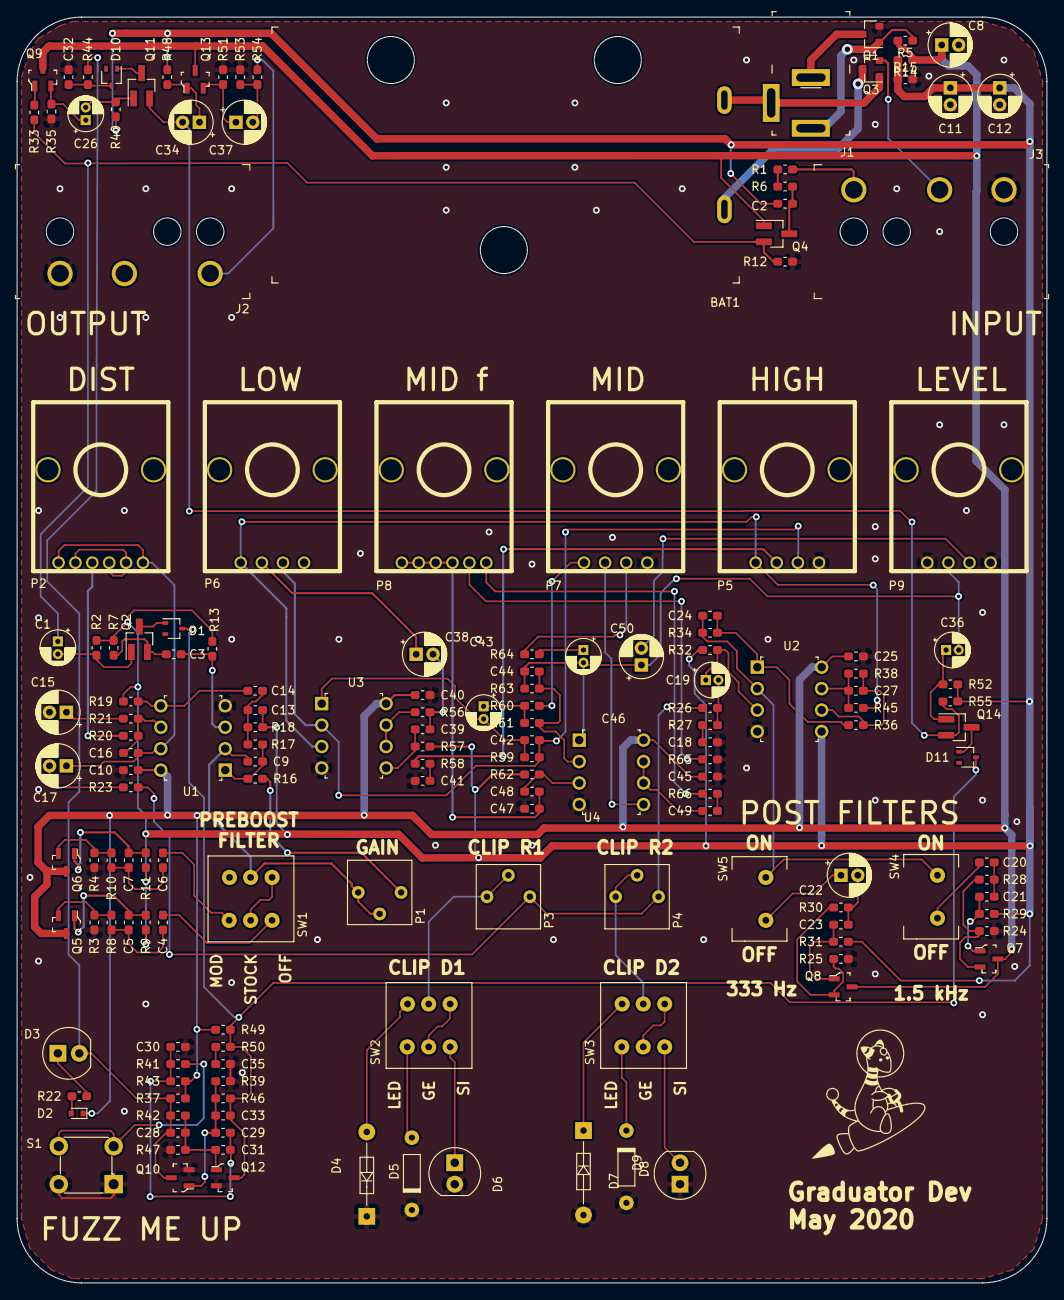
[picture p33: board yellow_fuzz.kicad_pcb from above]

Board: 2 copper layers, 121.9 x 149.9 mm, 164 parts (0 on the bottom side), 106 nets.

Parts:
BAT1: BC9VPC; Battery_Holder_9V_BC9VPC-ND
C1, C19, C26, C36, C43, C46: 1u; CP_Radial_D4.0mm_P1.50mm
C2, C5, C13, C23, C32, C35, C39: 47n; C_0603_1608Metric_Pad1.05x0.95mm_HandSolder
C3: 1.0u; C_0603_1608Metric_Pad1.05x0.95mm_HandSolder
C4, C10, C25, C40, C45, C48: 0.1u; C_0603_1608Metric_Pad1.05x0.95mm_HandSolder
C6: 27n; C_0603_1608Metric_Pad1.05x0.95mm_HandSolder
C7, C30, C41: 10n; C_0603_1608Metric_Pad1.05x0.95mm_HandSolder
C8, C11, C12: 100u; CP_Radial_D5.0mm_P2.00mm
C9, C44: 100p; C_0603_1608Metric_Pad1.05x0.95mm_HandSolder
C14: 33n; C_0603_1608Metric_Pad1.05x0.95mm_HandSolder
C15, C17, C34, C37, C50: 10u; CP_Radial_D5.0mm_P2.00mm
C16, C24: 47p; C_0603_1608Metric_Pad1.05x0.95mm_HandSolder
C18, C20: 15n; C_0603_1608Metric_Pad1.05x0.95mm_HandSolder
C21: 1.5n; C_0603_1608Metric_Pad1.05x0.95mm_HandSolder
C22, C38: 220n; CP_Radial_D5.0mm_P2.00mm
C27, C42: 10p; C_0603_1608Metric_Pad1.05x0.95mm_HandSolder
C28, C33: 470p; C_0603_1608Metric_Pad1.05x0.95mm_HandSolder
C29, C31: 220p; C_0603_1608Metric_Pad1.05x0.95mm_HandSolder
C47: 8.2n; C_0603_1608Metric_Pad1.05x0.95mm_HandSolder
C49: 22n; C_0603_1608Metric_Pad1.05x0.95mm_HandSolder
D1, D10, D11: BAS16W; SOT-323_SC-70
D2: DZ2S056X0L; D_SOD-523
D3, D6, D9: WP7113QBC_D; LED_5mm_Radial
D4, D7: 1N4148; Diode_DO-35_P10mm
D5, D8: 1N34A; DO-35
J1: PJ-202A; Barrel_Jack_5.5mmODx2.1mmID_PJ-202A
J2: RA49B11; Headphone_Jack_6.35mm_SN49B12B
J3: SN49B12B; Headphone_Jack_6.35mm_SN49B12B
P1: 3386P-1-204TLF; 3386P
P2: PTV112-4420A-A104; Potentiometer_Bourns_PTV112_3417A_Dual_Vertical
P3, P4: 3362P-1-102TLF; 3362PT
P5, P6, P7: PTV111-4420A-A104; Potentiometer_Bourns_PTV111_4420A_Single_Vertical
P8: PTV112-4420A-A503; Potentiometer_Bourns_PTV112_3417A_Dual_Vertical
P9: PTV111-4420A-A503; Potentiometer_Bourns_PTV111_4420A_Single_Vertical
Q1, Q3: DMN2041L; SOT-23
Q2, Q4, Q11, Q14: NSVJ3910SB3T1GOSCT-ND; SOT-23_Handsoldering
Q5, Q6, Q7, Q8, Q9, Q10, Q12, Q13: BC817-25-TP; SOT-23-3
R1, R3, R4, R12, R14, R15, R17, R18, R24, R25, R26, R33, R35, R51: 10k; R_0603_1608Metric_Pad1.05x0.95mm_HandSolder
R2, R13, R19, R32, R42, R46, R48, R53, R57: 100k; R_0603_1608Metric_Pad1.05x0.95mm_HandSolder
R5: 22; R_0603_1608Metric_Pad1.05x0.95mm_HandSolder
R6, R7, R40, R43, R44, R50, R52, R55, R62: 1M; R_0603_1608Metric_Pad1.05x0.95mm_HandSolder
R8, R10, R23, R56, R58, R65, R66: 2.2k; R_0603_1608Metric_Pad1.05x0.95mm_HandSolder
R9, R11, R29, R61, R63: 47k; R_0603_1608Metric_Pad1.05x0.95mm_HandSolder
R16, R20, R21, R28, R54: 1k; R_0603_1608Metric_Pad1.05x0.95mm_HandSolder
R22: 1.2k; R_0603_1608Metric_Pad1.05x0.95mm_HandSolder
R27: 4.7k; R_0603_1608Metric_Pad1.05x0.95mm_HandSolder
R30: 470; R_0603_1608Metric_Pad1.05x0.95mm_HandSolder
R31: 470k; R_0603_1608Metric_Pad1.05x0.95mm_HandSolder
R34: 3.3k; R_0603_1608Metric_Pad1.05x0.95mm_HandSolder
R36, R38, R45, R59: 22k; R_0603_1608Metric_Pad1.05x0.95mm_HandSolder
R37, R39, R47, R49: 56k; R_0603_1608Metric_Pad1.05x0.95mm_HandSolder
R41: 100; R_0603_1608Metric_Pad1.05x0.95mm_HandSolder
R60, R64: 330; R_0603_1608Metric_Pad1.05x0.95mm_HandSolder
S1: 1825910-6; Switch_Tactile_THT_6x6mm
SW1, SW2, SW3: SW_SP3T_A24JP; A24JP
SW4, SW5: SW_SPST_A11JP; A11JP
U1, U2, U3, U4: TL072CP; DIP-8_W7.62mm

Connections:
+4V: C11.1, C12.1, C13.1, R2.1, R6.1, R7.1, R9.2, R11.2, R13.1, R14.2, R15.1, R18.1, R19.1, R29.2, R31.2, R32.1, R40.1, R48.1, R52.1, R55.1, R57.2, R62.2, U2.5
+9V: C8.1, C10.1, C25.1, C40.1, C45.1, D2.1, Q4.1, Q5.3, Q6.3, Q7.3, Q8.3, Q9.3, Q13.3, R5.2, R14.1, R37.1, R43.1, R49.1, U1.8, U2.8, U3.8, U4.8
/BUFFERED_IN: C1.1, Q4.2, R12.1, R33.2
/BYPASS_EN: C28.1, D3.2, Q10.3, R37.2, R42.1, R44.2
/DIST_IN_EN: C33.2, D1.3, D11.3, Q12.3, R46.2, R49.2, R50.1
/INPUT_RING: J3.R, Q3.2
/SW_BASE_A: C28.2, C31.1, Q12.1, R42.2, R47.1
/SW_BASE_B: C29.1, C33.1, Q10.1, R39.1, R46.1
/SW_IN: R41.2, S1.3, S1.4
/SW_IN_DB: C29.2, C30.1, C31.2, R41.1, R43.2
/tone_block/TONE_IN: P5.1, P6.1, R45.1, U3.3
/tone_block/TONE_OUT: C36.2, C44.1, C46.2, C50.1, P9.2, R63.1, U4.1
GND: C8.2, C10.2, C11.2, C12.2, C15.2, C18.2, C25.2, C30.2, C32.2, C35.2, C40.2, C41.2, C45.2, C47.2, D4.1, D5.K, D6.2, D7.2, D8.A, D9.1, J2.S, J3.S, P5.4, P7.4, P9.1, P9.4, Q1.2, Q10.2, Q12.2, R3.2, R4.2, R12.2, R15.2, R24.2, R25.2, R35.2, R39.2, R47.2, R51.2, R53.2, R65.2, S1.1, S1.2, U1.4, U2.4, U3.4, U4.4
unnamed: BAT1.NEG, Q3.3
unnamed: BAT1.POS, J1.3, Q3.1
unnamed: C1.2, Q2.1, R2.2
unnamed: C2.1, Q4.3, R6.2
unnamed: C2.2, R1.1
unnamed: C3.1, R13.2, U1.3
unnamed: C3.2, Q2.2, R7.2
unnamed: C4.1, SW1.6
unnamed: C4.2, C5.1, R8.1
unnamed: C5.2, Q5.1, R9.1
unnamed: C6.1, SW1.4
unnamed: C6.2, C7.1, R10.1
unnamed: C7.2, Q6.1, R11.1
unnamed: C9.1, R16.1, R17.2, U1.1
unnamed: C9.2, P1.1, P1.2, SW1.2, U1.2
unnamed: C13.2, C14.2, R17.1, R18.2
unnamed: C14.1, R19.2, U1.5
unnamed: C15.1, R21.2
unnamed: C16.1, C17.1, P2.5, P2.6, U1.7
unnamed: C16.2, R20.2, R21.1, U1.6
unnamed: C17.2, R23.2
unnamed: C18.1, R27.2
unnamed: C19.1, R32.2, U2.3
unnamed: C19.2, R26.1, R27.1
unnamed: C20.1, SW4.1
unnamed: C20.2, C21.1, R28.1
unnamed: C21.2, Q7.1, R29.1
unnamed: C22.1, SW5.1
unnamed: C22.2, C23.1, R30.1
unnamed: C23.2, Q8.1, R31.1
unnamed: C24.1, R34.1, R36.2, U2.1
unnamed: C24.2, R34.2, SW4.3, SW5.3, U2.2
unnamed: C26.1, Q9.2, R35.1
unnamed: C26.2, Q11.1, R40.2
unnamed: C27.1, R38.1, R45.2, U2.7
unnamed: C27.2, R36.1, R38.2, U2.6
unnamed: C32.1, D10.3, R44.1
unnamed: C34.1, Q13.1, R48.2
unnamed: C34.2, Q11.2, Q14.2, R55.2
unnamed: C35.1, R50.2
unnamed: C36.1, Q14.1, R52.2
unnamed: C37.1, Q13.2, R51.1
unnamed: C37.2, R53.1, R54.2
unnamed: C38.1, P6.2
unnamed: C38.2, C39.1, R56.1
unnamed: C39.2, R57.1, U3.5
unnamed: C41.1, R58.2
unnamed: C42.1, C43.2, R59.1, U3.1
unnamed: C42.2, P5.3, P6.3, R59.2, U3.2
unnamed: C43.1, R60.1, R61.2
unnamed: C44.2, R61.1, R63.2, U4.2
unnamed: C46.1, R64.1
unnamed: C47.1, C48.1, P8.1, P8.2, P8.4, P8.5
unnamed: C48.2, R62.1, U4.3
unnamed: C49.1, U4.6, U4.7
unnamed: C49.2, R66.1
unnamed: C50.2, P9.3
unnamed: D1.1, Q2.3
unnamed: D2.2, R22.1
unnamed: D3.1, R22.2
unnamed: D4.2, SW2.1
unnamed: D5.A, SW2.4
unnamed: D6.1, SW2.6
unnamed: D7.1, SW3.1
unnamed: D8.K, SW3.4
unnamed: D9.2, SW3.6
unnamed: D10.1, Q11.3
unnamed: D11.1, Q14.3
unnamed: J1.1, Q1.1, R5.1
unnamed: J1.2, Q1.3
unnamed: J2.T, R54.1
unnamed: J3.T, R1.2
unnamed: P1.3, R16.2
unnamed: P2.1, R20.1
unnamed: P2.2, P2.3, P2.4
unnamed: P3.1, P3.2, SW2.2
unnamed: P3.3, P4.3, R23.1, R26.2
unnamed: P4.1, P4.2, SW3.2
unnamed: P5.2, R58.1
unnamed: P7.1, R60.2
unnamed: P7.2, U4.5
unnamed: P7.3, R64.2
unnamed: P8.3, R65.1
unnamed: P8.6, R66.2
unnamed: Q5.2, R3.1, R8.2
unnamed: Q6.2, R4.1, R10.2
unnamed: Q7.2, R24.1, R28.2
unnamed: Q8.2, R25.1, R30.2
unnamed: Q9.1, R33.1
unnamed: R56.2, U3.6, U3.7
unnamed: SW1.3, SW1.5
unnamed: SW2.3, SW2.5
unnamed: SW3.3, SW3.5

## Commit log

2020-01-24 did a bunch of sims and made a readme, schematic capture time
    [yellow_fuzz_dev.kicad_pcb, yellow_fuzz_dev.sch]
2020-01-31 sourced all resistors and caps, need to create new footprints for potentiometers.
    [yellow_fuzz_dev.sch]
2020-02-02 adding footprints for new pots
    [PTV111-4420A.stp, pcl1d-c24-bab.stp, pcw1j-b24-kcb.stp]
2020-02-04 added some new candidate parts
    [EDI2CAP.CFG, FS5700SPMT2B2M2QE.stp, chips.prt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]
2020-02-04 pulling parts in for schematic capture
    [RA49B12A.STEP, ptv112-3417a-xxxxx.stp, yellow_fuzz_dev.sch]
2020-02-06 schematic capture in progress
    [yellow_fuzz_dev.sch]
2020-02-13 placing symbols for EQ section
    [yellow_fuzz_dev.sch]
2020-03-29 captured tone, power, and switching sections.
    [yellow_fuzz_dev.sch]
2020-03-29 added power jack
    [yellow_fuzz_dev.sch]
2020-04-03 power section and interconnect done
    [yellow_fuzz_dev.sch]
2020-04-03 Changed qual op amps to duals for easy swapping
    [yellow_fuzz_dev.sch]
2020-04-03 reviewing all filter setpoints, just made it to distortion section
    [yellow_fuzz_dev.sch]
2020-04-21 woo boy I dunno buncha progress probably
    [A11JP.stp, A24JP.stp, tone_block.sch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]
2020-04-22 moved footprints into PCB
    [3362P001XXX0A.stp, 3386P(T).stp, tone_block.sch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]
2020-04-22 added 3d to connector and DIP footprints, moved to project lib, updated PCB
    [3362-T.stp, BC9VPC.STEP, CUI_DEVICES_PJ-202A.step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]
2020-04-27 updated potentiometers to use the same mechanical family throughout
    [tone_block.sch, yellow_fuzz_dev.sch]
2020-04-28 placement partially done
    [yellow_fuzz_dev.kicad_pcb]
2020-04-28 first draft placement done. Added ampharos logo.
    [tone_block.sch, yellow_fuzz_dev.kicad_pcb, yellow_fuzz_dev.sch]
2020-04-30 did a bunch of routing and rounded the corners
    [yellow_fuzz_dev.kicad_pcb]
2020-05-01 routing complete and DRC clear
    [yellow_fuzz_dev.kicad_pcb]
2020-05-02 BOM messings-about. Kicad is terrible at this
    [graduator_dev_rev1_bom.csv]
2020-05-02 corrected BOM fields and generated BOM
    [tone_block.sch, yellow_fuzz_dev.kicad_pcb, yellow_fuzz_dev.sch]
2020-05-02 generated gerbers, BOM, and sch - releasing dev to fab
    [graduator_dev_rev1_bom.csv, tone_block.sch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]
2020-05-02 regenerated gerbers and drill files
    [yellow_fuzz_dev-B_Cu.gbl, yellow_fuzz_dev-B_Mask.gbs, yellow_fuzz_dev-Edge_Cuts.gm1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]
2020-05-02 saving changes?
    [yellow_fuzz_dev.kicad_pcb]
2021-09-15 created form-factor project directory, copied project over and resolved library bcrap, added board outline sketch, added symbols for new threaded pots to library, still need footprints.
    [tone_block.sch, yellow_fuzz.kicad_pcb, yellow_fuzz.sch]
2021-09-20 added new potentiometer footprint to lib but it isn't linked right yet

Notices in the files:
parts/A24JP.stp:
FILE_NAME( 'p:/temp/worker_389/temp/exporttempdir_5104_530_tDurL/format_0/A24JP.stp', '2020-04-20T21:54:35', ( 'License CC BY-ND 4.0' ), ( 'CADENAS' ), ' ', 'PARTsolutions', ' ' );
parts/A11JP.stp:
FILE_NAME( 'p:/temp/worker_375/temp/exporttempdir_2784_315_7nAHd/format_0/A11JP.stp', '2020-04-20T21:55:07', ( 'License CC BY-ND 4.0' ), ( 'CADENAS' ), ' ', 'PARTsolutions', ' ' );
